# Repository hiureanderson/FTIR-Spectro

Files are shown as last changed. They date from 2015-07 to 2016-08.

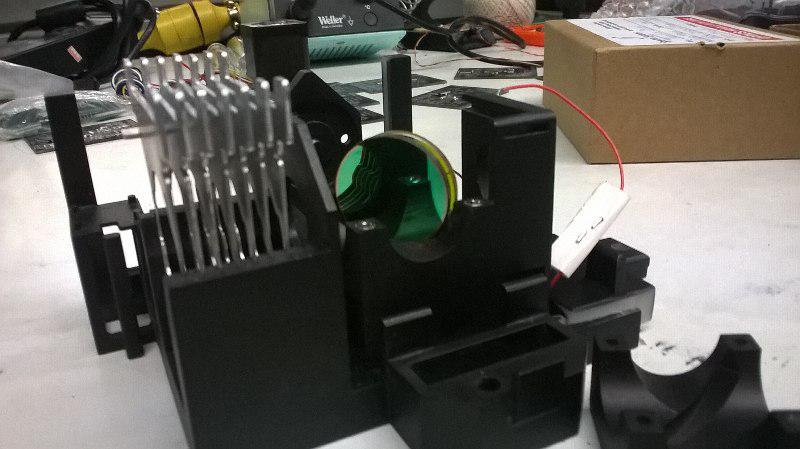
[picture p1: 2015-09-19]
pictures/photo_2015-09-12_13-56-02.jpg

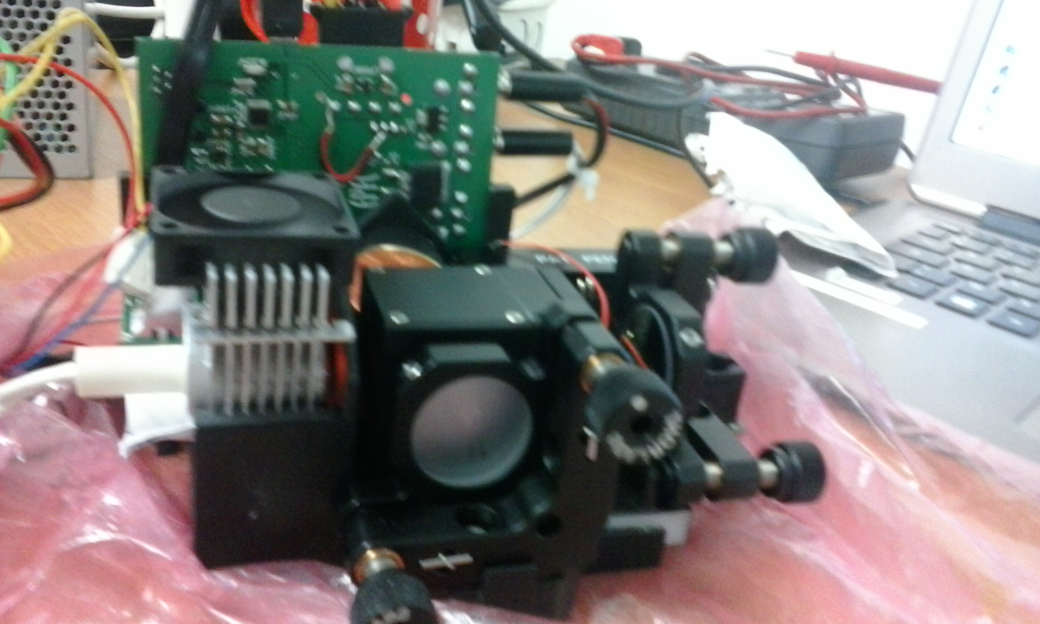
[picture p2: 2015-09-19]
pictures/IMG_20150918_115155.jpg

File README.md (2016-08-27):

# FTIR-Spectro

A DIY Infrared spectrometry project based on michelson interferometry and Fourrier transform analysis
The system relies on a Atmega32u4 MCU as its core and the code is developed using the abstracted Arduino environment.

## What is the current state ?

Last Update: 27.08.2016
The FTIR DIY spectrometer is currently in stanbye and needs students for the project to continue on.
The project is currently based at Octanis Assocation, in the Hackuarium Hackerspace in Renens, Switzerland.
More can be found on these organisations at:

  http://octanis.org   
  http://wiki.hackuarium.ch/w/Main_Page
  
## What needs to be done ?

* Change CAD so that material swelling due to water uptake is taken into account (or change Nylon for a more stable material)
* Retest the stability of the AC-DC network 96V rectifier down to mV oscillations
* Make a proper PCB board for the 96V rectifier with BOM and dedicated documentation and Specs
* Align the mirrors system with a laser
* Test the mirror displacement due to the piezo crystal with a laser and charaterize it
* Program the Atmega MCU to drive the DAC output and test this output voltage (it might be necessary to reorder a board)
* Couple the Atmega MCU to the 0-5V --> 0-96V converter and charaterize the output voltage
* Test the Control of the piezo dilatation with the Atmega and the 0-96V output you charaterized
* Determine if the sensor sensitivity is high enough, if not various options can be explored: change the amplifier resistor bridge, cool the sensor down to -50°C with a Peltier dedicated device to reduce SNR, test a PIR type of sensor, find a more suited sensor.
* Once this stage is complete determine how much light is lost passing in the PE liquid holding cell when empty and scan with the piezo to get the empty cell response (need to program a control loop on the MCU with sensor reading)
* Test the device with different liquids and perform fft on the data provided by the Atmega board to get spectra
* Charaterize for ammonia detection
* Provide a deliverable kit with user manual

Each step must be documented so no work is lost and the community can enjoy the results !!

## Contact

You can contact me concerning the project at quentin.cabrol@gmail.com.
We are currently searching for members to enroll and work on this project

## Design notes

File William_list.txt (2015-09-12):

Order From William

002X 350mA 100VDC --> ok
http://www.alibaba.com/product-detail/50W-constant-current-Single-output-Non_60109745699.html

001X PE HDPE 0.5mm thick A4 sheet (no PVC !! pure PE only !)

010X DIN 934 hex Nut M2
010X DIN 934 hex Nut M4
005X DIN 912 hex Screw M2 13mm
005X DIN 912 hex Screw M2 25mm
005X DIN 912 hex Screw M4 20mm
005X UNC 4-40 screw 7-8mm

200X Thread Forming screw M3 5mm
http://www.alibaba.com/product-detail/Security-pozi-screw-m3x5-stainless-steel_60266052503.html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

Mica sheets (0.1mm 30X20mm) 

1st quote
led power=12usd/pcs X2          24
A4 0.5MM pe roll=2usd/pcs X4    28
Screw and nuts=20usd            48
3d print total=220usd          268
Mica sheet.could I make it 4$  272

/////////////////////////////////////////////////////////////////////////////////////////////////////////////////////////////////

2nd order for Solar Decathlon

20X raspi 2 model B plastic enclosure
20X short USB micro cables 15cm
20X raspi 2 USB power supply
20X 5m length RJ45 cables category 6
20X 16Go Sandisk quality SD card

First quote
20X raspi 2 model B plastic enclosure 2$/pcs		40
20X short USB micro cables    2$/pcs			80
20X raspi 2 USB power supply with line  6$/pcs		200
20X 5m length RJ45 cables category 6  5$/pcs		300
20X 16Go Sandisk quality SD card. 10$/pcs		500

Added to the initial 290 USD first order --> 800 USD
Shipping --> about 100 USD 
William compensation --> 50DUSD 
Grand total 950 USD
With 250 USD dedicated to FTIR

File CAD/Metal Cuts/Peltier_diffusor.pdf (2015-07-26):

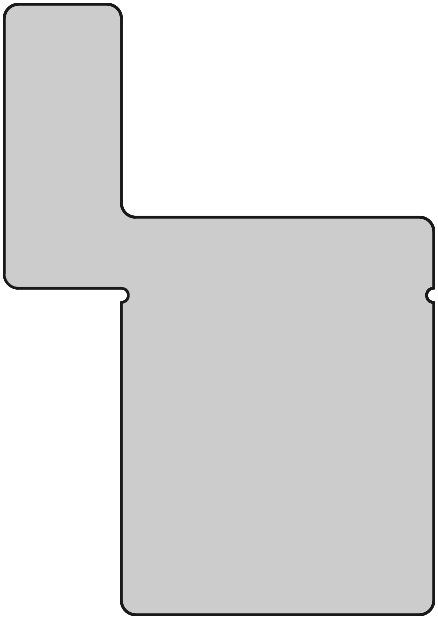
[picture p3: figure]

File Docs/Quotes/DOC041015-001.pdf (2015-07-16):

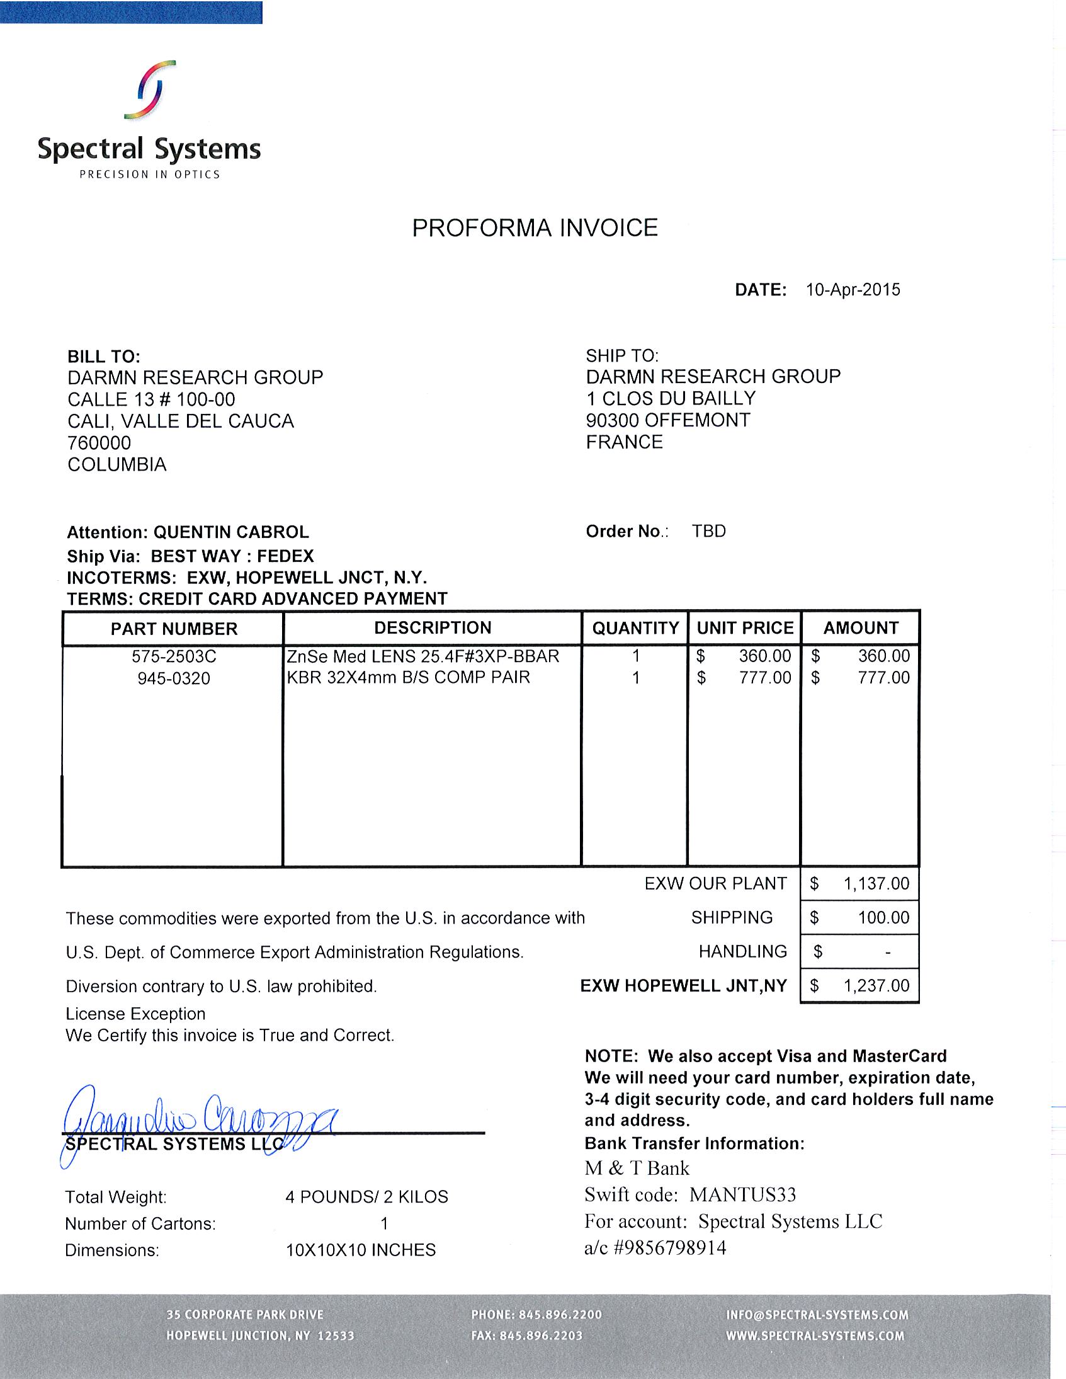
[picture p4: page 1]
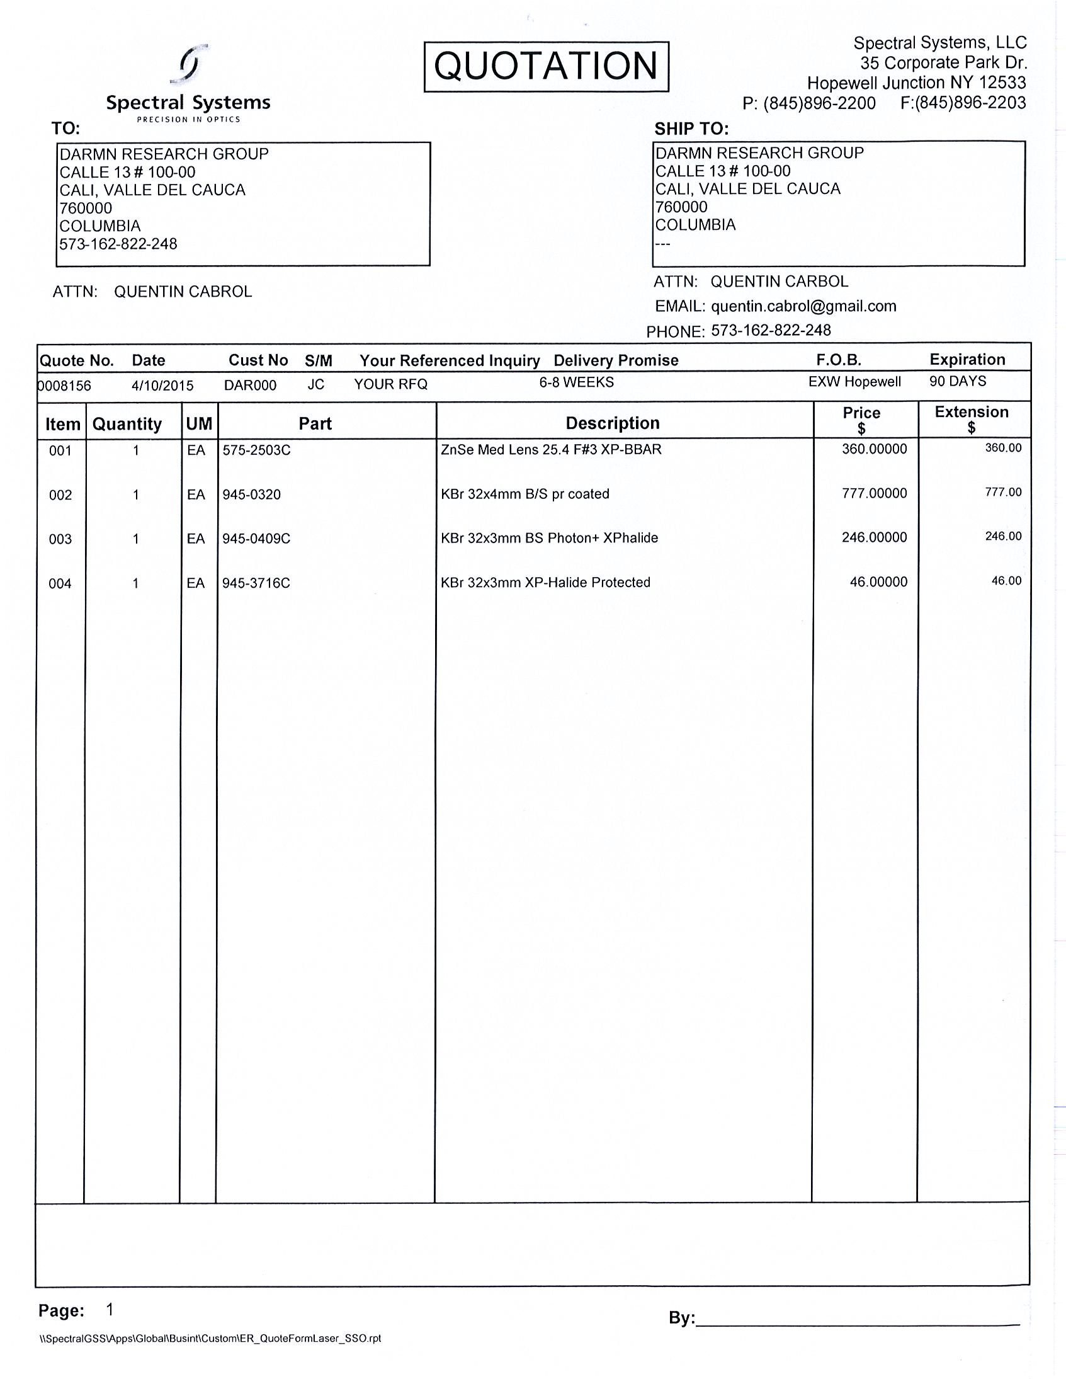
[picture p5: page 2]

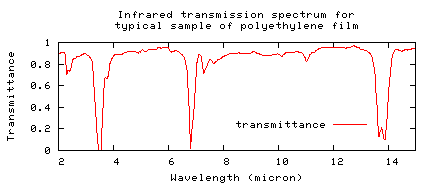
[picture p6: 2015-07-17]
Docs/Datasheets/HDPE_spectrum.png

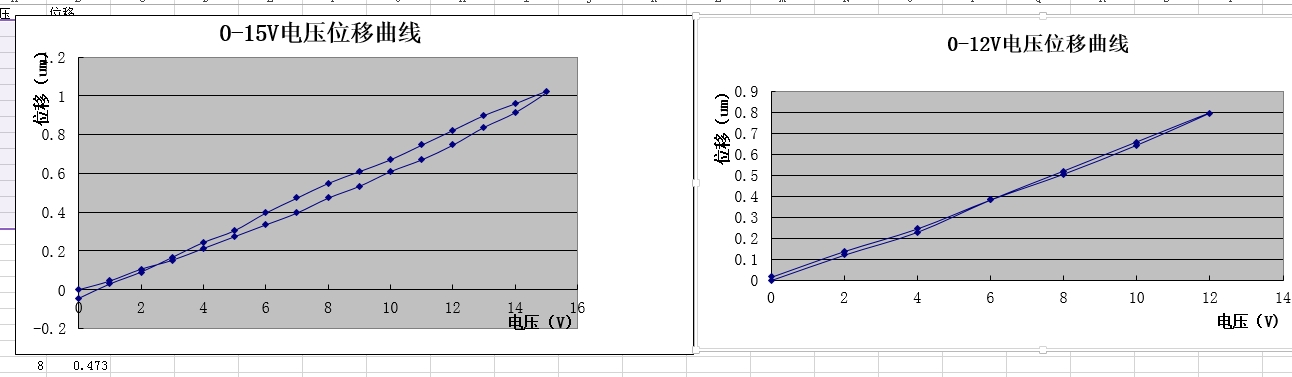
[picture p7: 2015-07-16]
Docs/Datasheets/Piezo_specs.jpg

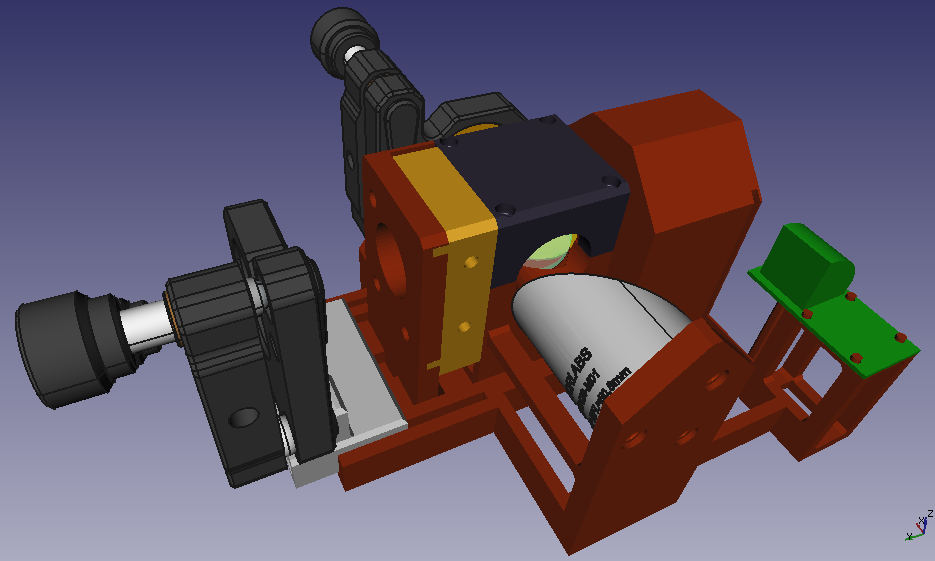
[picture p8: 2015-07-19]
pictures/Full_FTIR.png

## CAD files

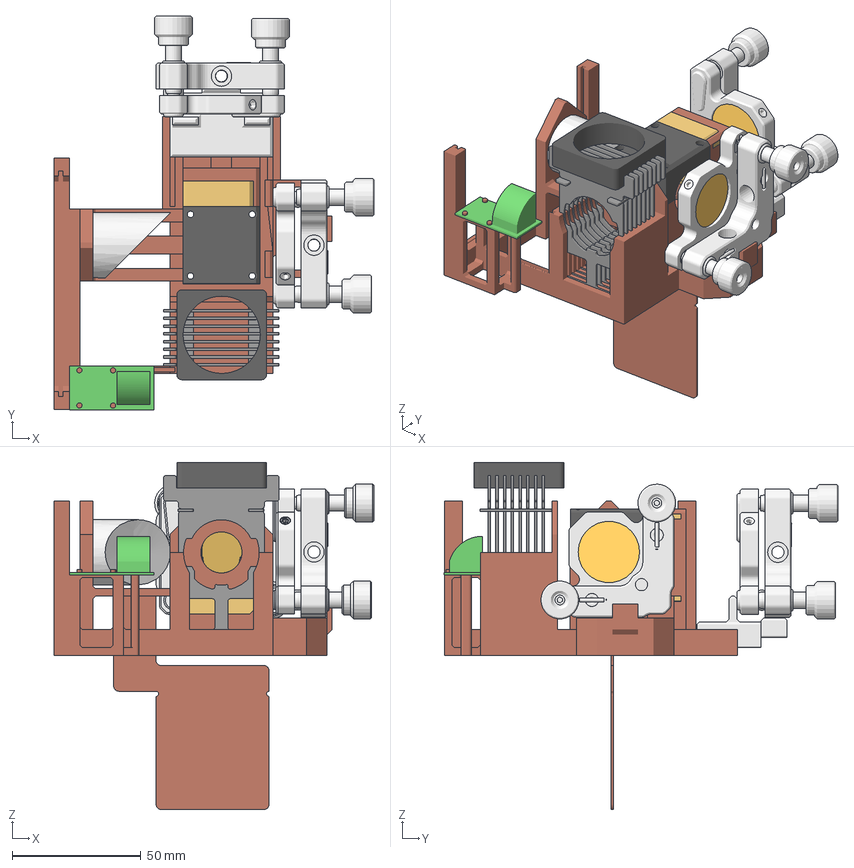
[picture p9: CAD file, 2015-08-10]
CAD/Assembly_6.fcstd
124.4 x 153.1 x 135.0 mm
6628-E0W
6628-E0W001
6628-E0W002
6628-E0W003
6628-E0W004
6628-E0W005
6628-E0W006
6628-E0W007
6628-E0W008
6628-E0W009
6628-E0W010
6628-E0W011
6628-E0W012
6628-E0W013
6628-E0W014
6628-E0W015
6628-E0W016
6628-E0W017
6628-E0W018
6628-E0W019
6628-E0W020
6628-E0W021
6628-E0W022
6628-E0W023
6628-E0W024
6628-E0W025
6628-E0W026
6628-E0W027
6628-E0W028
6628-E0W029
6628-E0W030
6628-E0W031
6628-E0W032
6628-E0W033
TTN034384-E0W
Splitter
Splitter001
Mirror
Mirror001
Holder
Charriot
ZTP115
Splitter_hat
Fan_IR
Heat_slit
Heat_slit001
Heat_slit002
Heat_slit003
Heat_slit004
Heat_slit005
Heat_slit006
Heat_slit007
Heat_slit_holder
Heat_slit_holder001
Peltier_diffusor
Bench_new

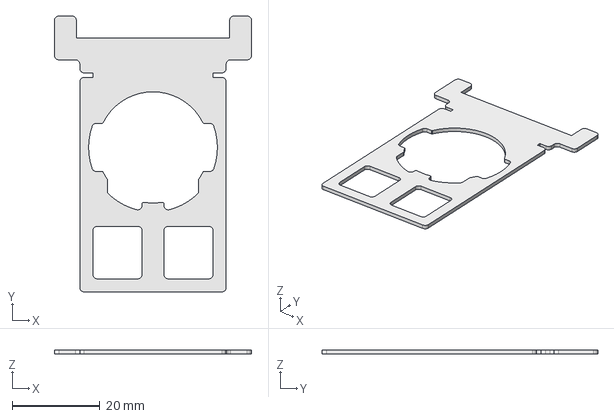
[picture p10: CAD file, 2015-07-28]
CAD/Metal Cuts/MetalCut.fcstd
45.0 x 63.0 x 1.00 mm

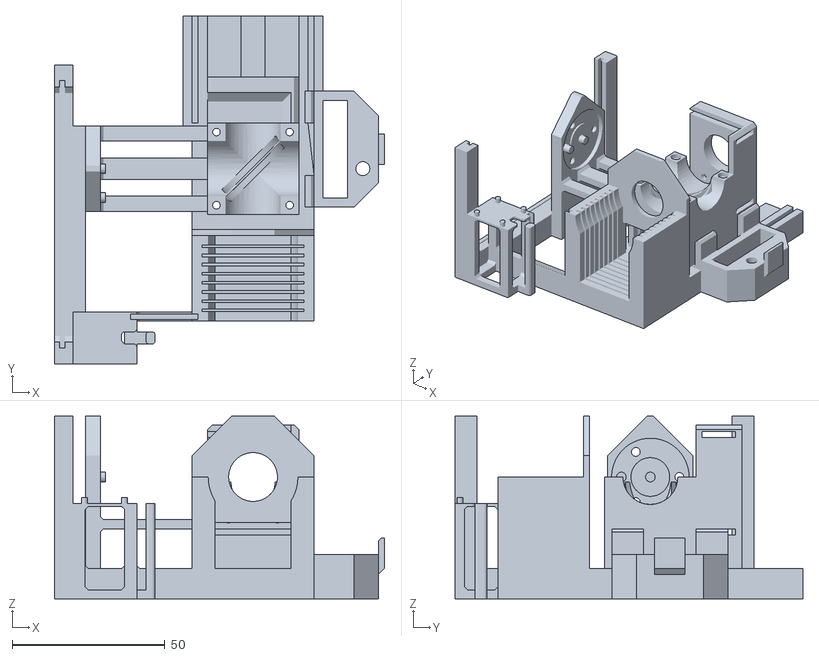
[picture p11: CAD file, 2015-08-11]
CAD/STL/Bench_new.stl
108.2 x 114.0 x 60.0

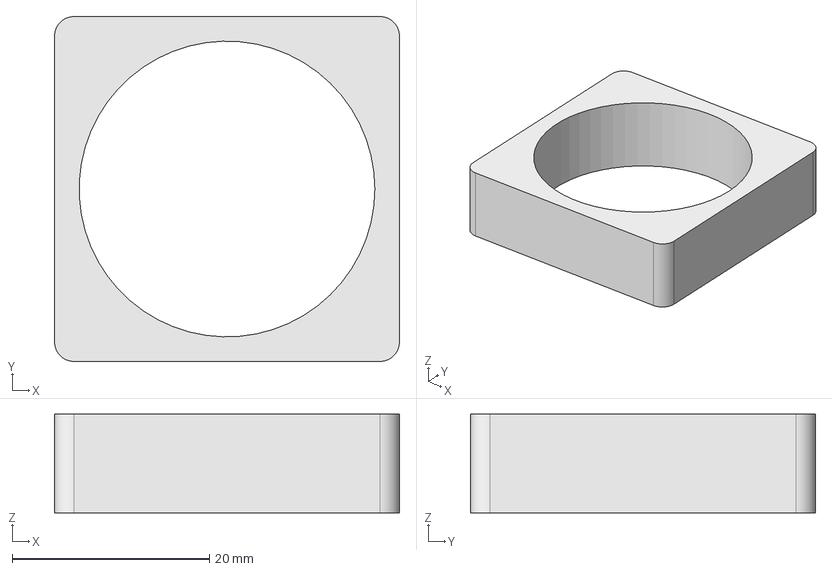
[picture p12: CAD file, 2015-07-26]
CAD/IR_fan.fcstd
35.0 x 35.0 x 10.0 mm

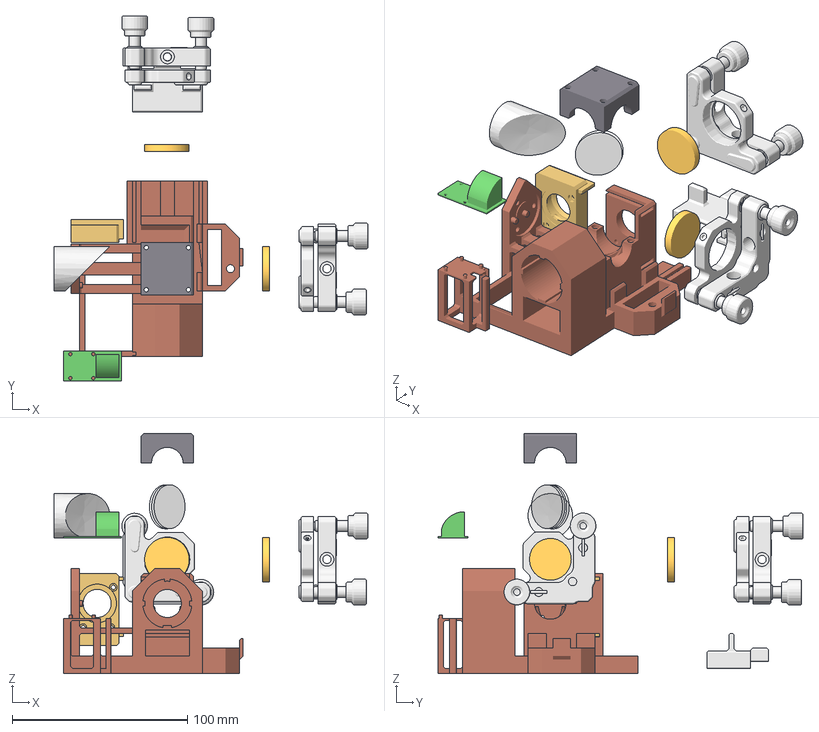
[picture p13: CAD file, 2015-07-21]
CAD/Eclate.fcstd
178.9 x 208.1 x 137.0 mm
6628-E0W
6628-E0W001
6628-E0W002
6628-E0W003
6628-E0W004
6628-E0W005
6628-E0W006
6628-E0W007
6628-E0W008
6628-E0W009
6628-E0W010
6628-E0W011
6628-E0W012
6628-E0W013
6628-E0W014
6628-E0W015
6628-E0W016
6628-E0W017
6628-E0W018
6628-E0W019
6628-E0W020
6628-E0W021
6628-E0W022
6628-E0W023
6628-E0W024
6628-E0W025
6628-E0W026
6628-E0W027
6628-E0W028
6628-E0W029
6628-E0W030
6628-E0W031
6628-E0W032
6628-E0W033
TTN034384-E0W
Splitter
Splitter001
Mirror
Mirror001
Holder
Charriot
ZTP115
Splitter_hat
Bench

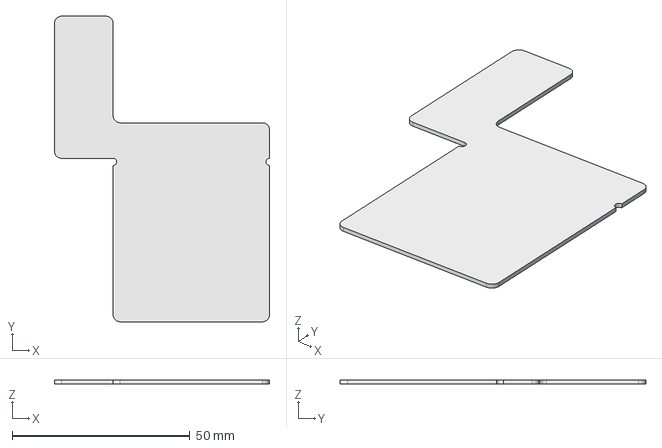
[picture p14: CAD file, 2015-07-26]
CAD/Metal Cuts/Peltier_diffusor.fcstd
60.5 x 86.0 x 1.00 mm

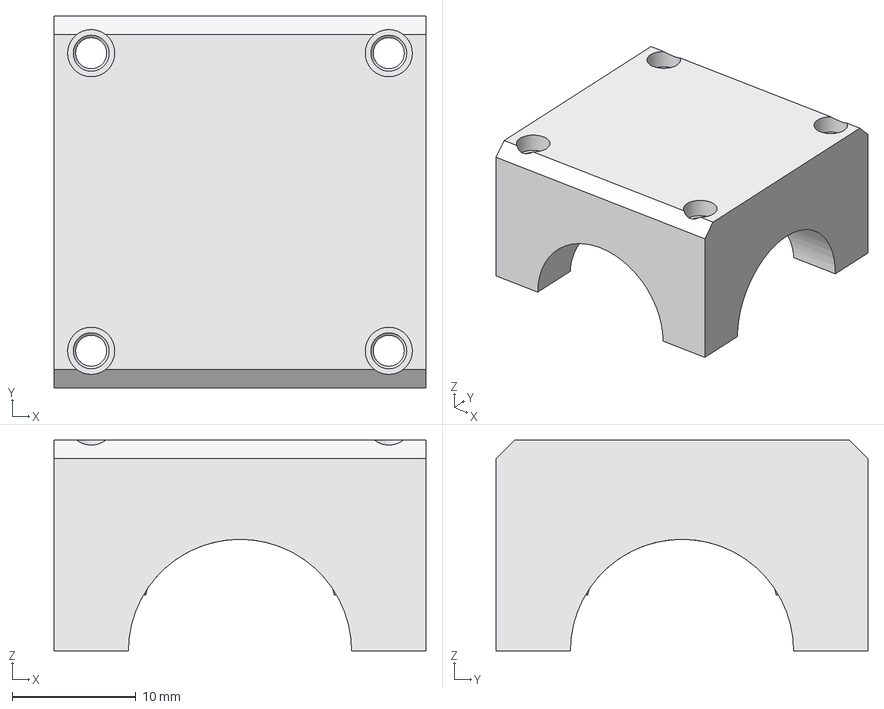
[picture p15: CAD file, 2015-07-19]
CAD/Splitter_Hat_1.fcstd
30.0 x 30.0 x 17.0 mm

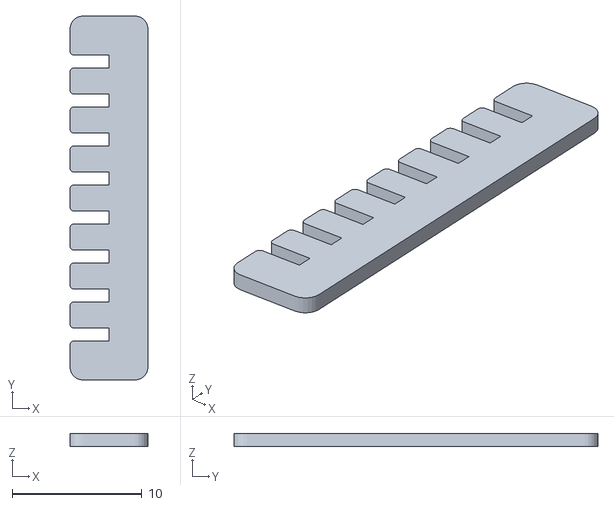
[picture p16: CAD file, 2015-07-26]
CAD/STL/Heat_slit_holder.stl
6.00 x 28.0 x 1.00

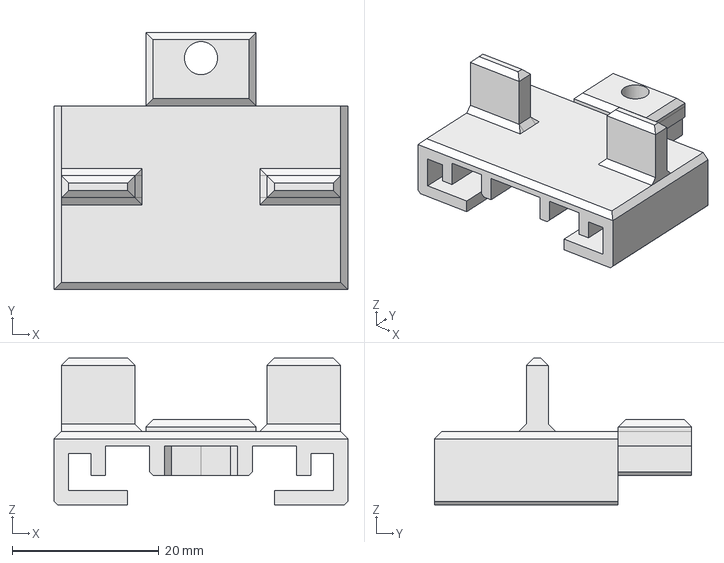
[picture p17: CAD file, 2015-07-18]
CAD/Charriot_2.fcstd
40.0 x 35.0 x 20.0 mm

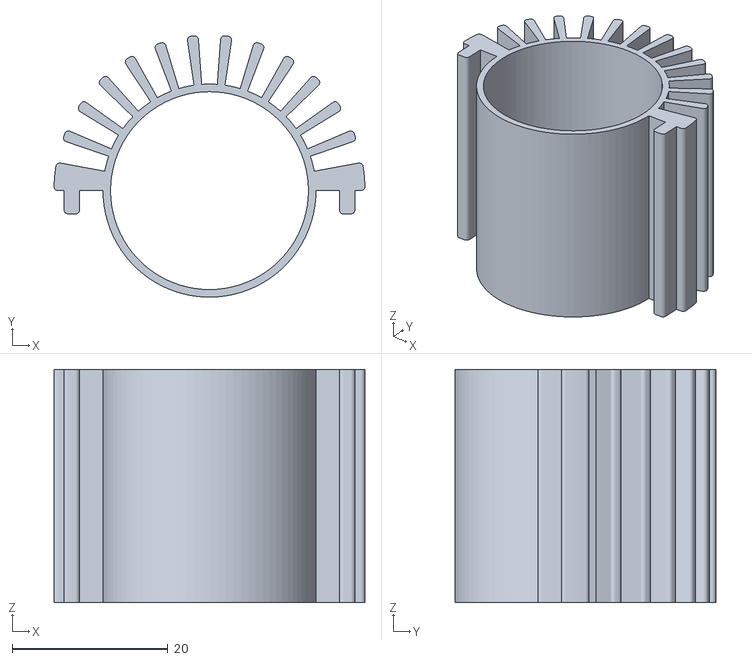
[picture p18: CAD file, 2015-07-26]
CAD/STL/Heat_sink.stl
40.0 x 33.6 x 30.0

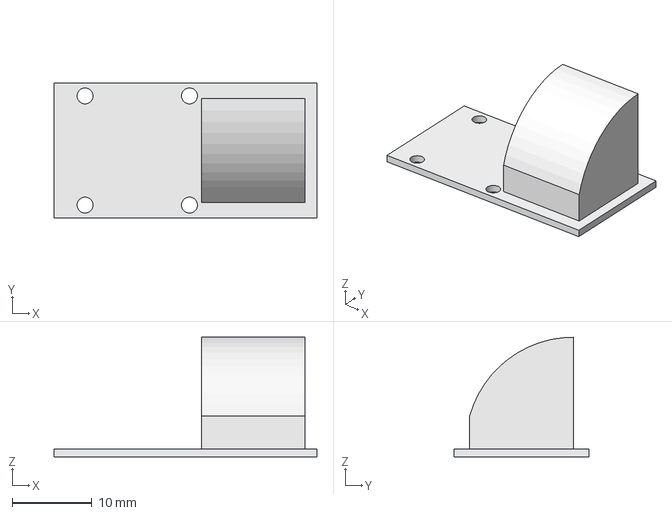
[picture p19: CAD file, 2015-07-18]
CAD/Sensor_ZTP115.fcstd
33.0 x 17.0 x 15.0 mm

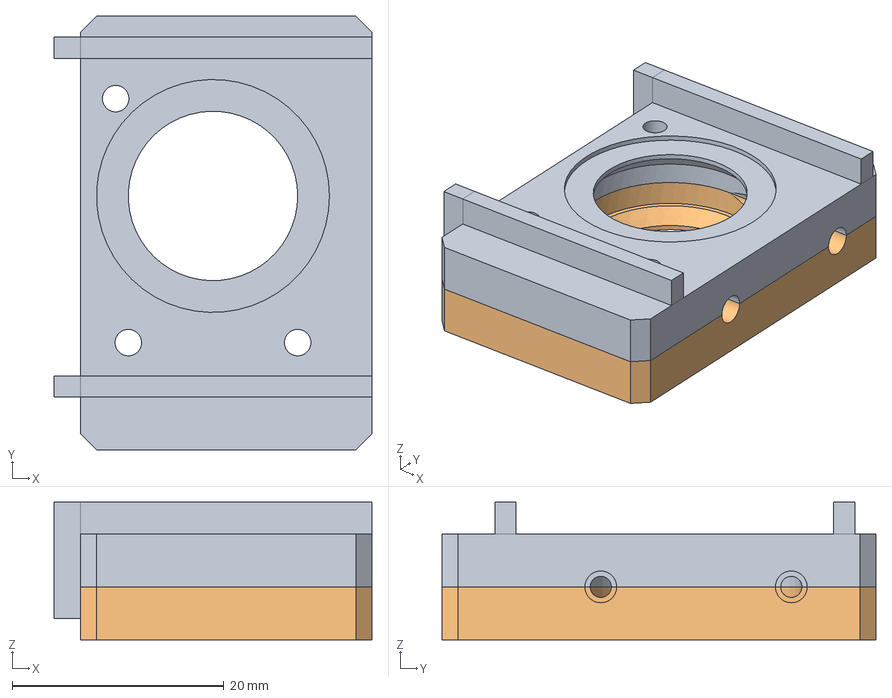
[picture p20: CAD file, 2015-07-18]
CAD/Sample_holder_3.fcstd
30.0 x 41.0 x 13.0 mm

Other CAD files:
CAD/Metal Cuts/Heat_slit.dwg
CAD/STL/Fan_IR.stl
CAD/STL/Peltier_diffusor.stl
CAD/Metal Cuts/Heat_slit_holder.dwg
CAD/Metal Cuts/Slits_holder.fcstd
CAD/STL/Heat_slit.stl
CAD/FTIR.fcstd
CAD/Metal Cuts/Peltier_diffusor.dwg
CAD/Mirror.fcstd
CAD/STL/Charriot.stl
CAD/STL/Holder.stl
CAD/STL/KM100-Step.step
CAD/STL/MPD129-M01-Step.step
CAD/STL/Mirror.stl
CAD/STL/Splitter.stl
CAD/STL/Splitter_hat.stl
CAD/STL/ZTP115.stl
CAD/Sample_holder_2.fcstd
CAD/Splitter.fcstd

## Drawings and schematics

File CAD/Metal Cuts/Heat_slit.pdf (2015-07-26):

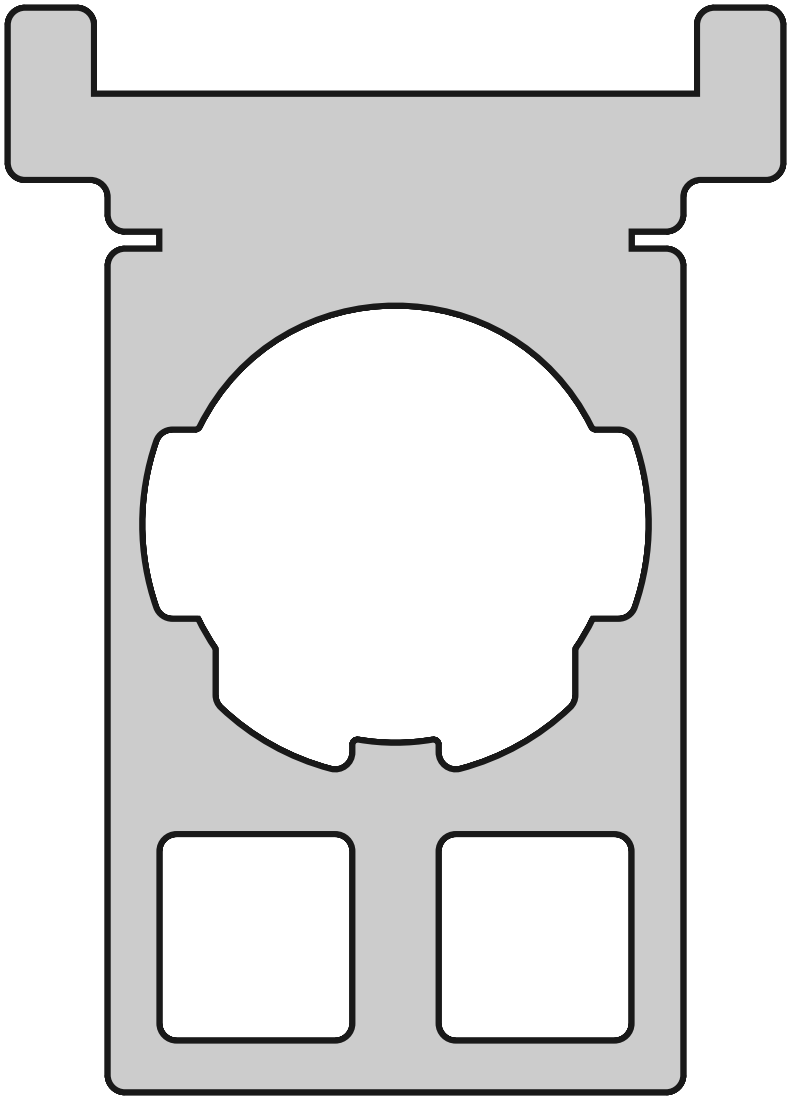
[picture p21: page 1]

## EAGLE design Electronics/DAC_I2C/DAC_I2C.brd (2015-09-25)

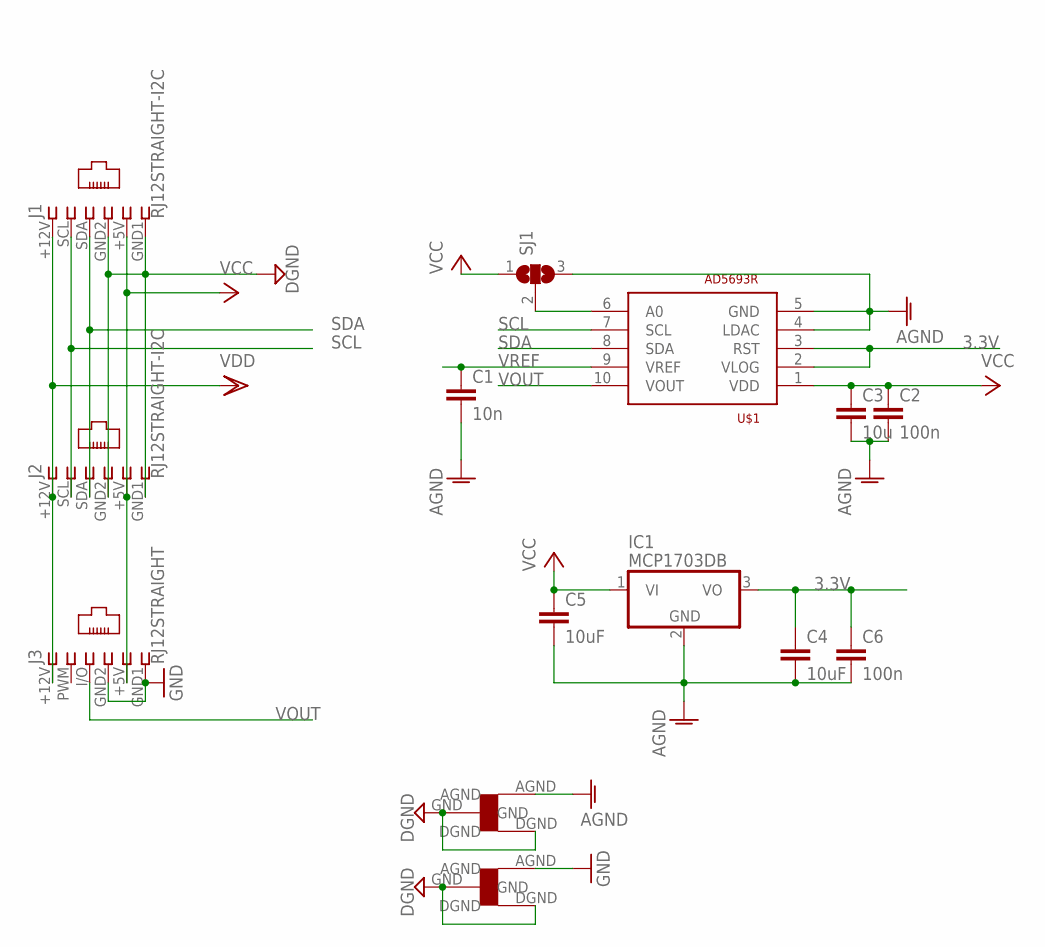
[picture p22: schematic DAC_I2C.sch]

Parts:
C1: 10n; C1206
C2, C6: 100n; C1206
C3: 10u; C1206
C4, C5: 10uF; C1206
IC1: MCP1703DB; SOT223
J1, J2: RJ12STRAIGHT-I2C; RJ12-STRAIGHT-I2C
J3: RJ12STRAIGHT; RJ12-STRAIGHT
SJ1: SJ2W; SJ_2
U$1: AD5693R; MSOP10
U$2, U$5: STARGND; STAR

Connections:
3.3V: C4.1, C6.1, IC1.3 (VO), U$1.2 (VLOG), U$1.3 (RST)
AGND: C1.2, C2.2, C3.2, C4.2, C5.2, C6.2, IC1.2 (GND), SJ1.3, U$1.4 (LDAC), U$1.5 (GND), U$5.AGND
DGND: J1.GND1 (6), J1.GND2 (4), J2.GND1 (6), J2.GND2 (4), U$2.DGND, U$2.GND, U$5.DGND, U$5.GND
GND: J3.GND1 (6), J3.GND2 (4), U$2.AGND
unnamed: SJ1.2, U$1.6 (A0)
SCL: J1.SCL (2), J2.SCL (2), U$1.7 (SCL)
SDA: J1.SDA (3), J2.SDA (3), U$1.8 (SDA)
VCC: C2.1, C3.1, C5.1, IC1.1 (VI), J1.+5V (5), J2.+5V (5), J3.+5V (5), SJ1.1, U$1.1 (VDD)
VDD: J1.+12V (1), J2.+12V (1), J3.+12V (1)
VOUT: J3.I/O (3), U$1.10 (VOUT)
VREF: C1.1, U$1.9 (VREF)

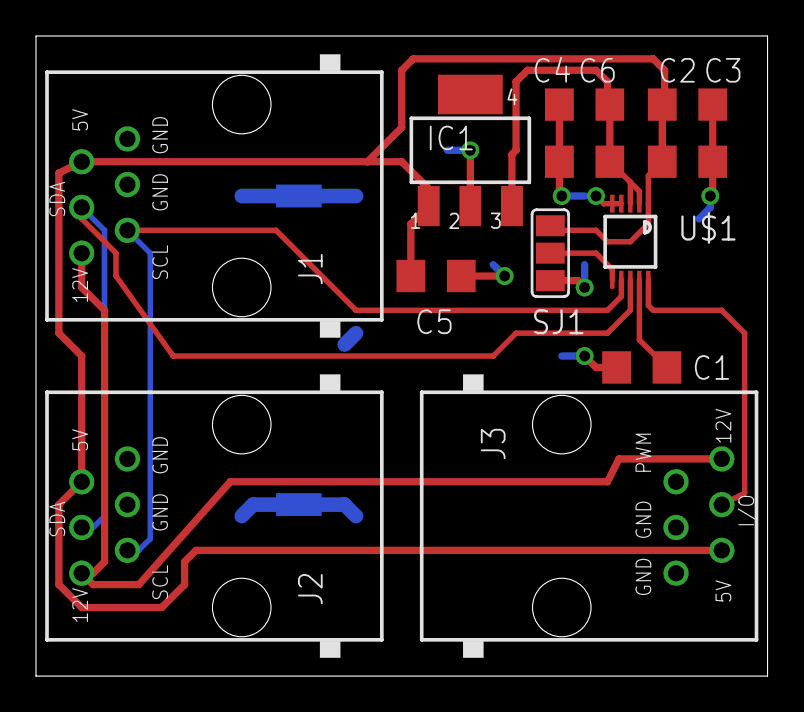
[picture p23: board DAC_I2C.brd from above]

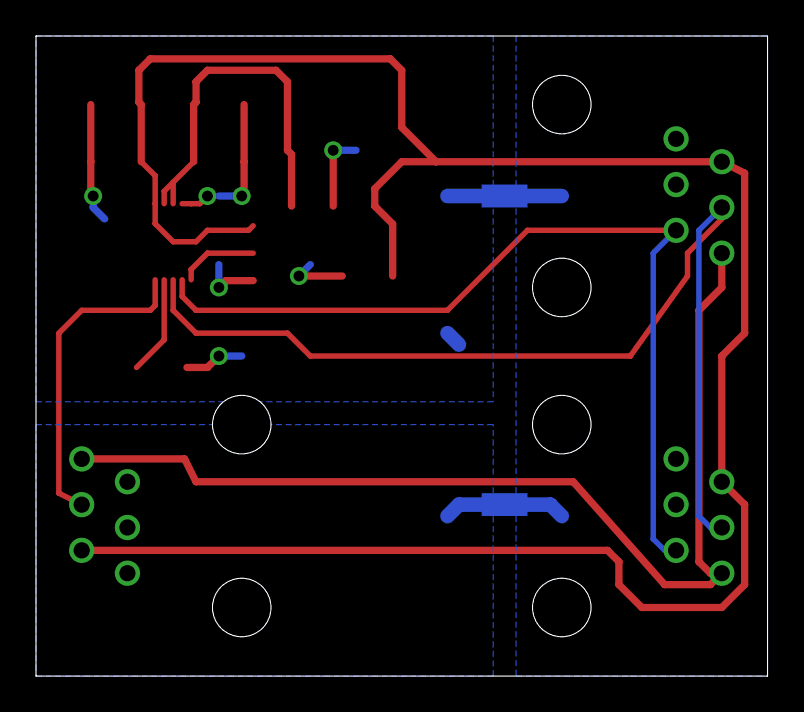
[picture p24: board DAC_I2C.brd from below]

Board: 2 copper layers, 40.6 x 35.6 mm, 14 parts (2 on the bottom side), 11 nets.

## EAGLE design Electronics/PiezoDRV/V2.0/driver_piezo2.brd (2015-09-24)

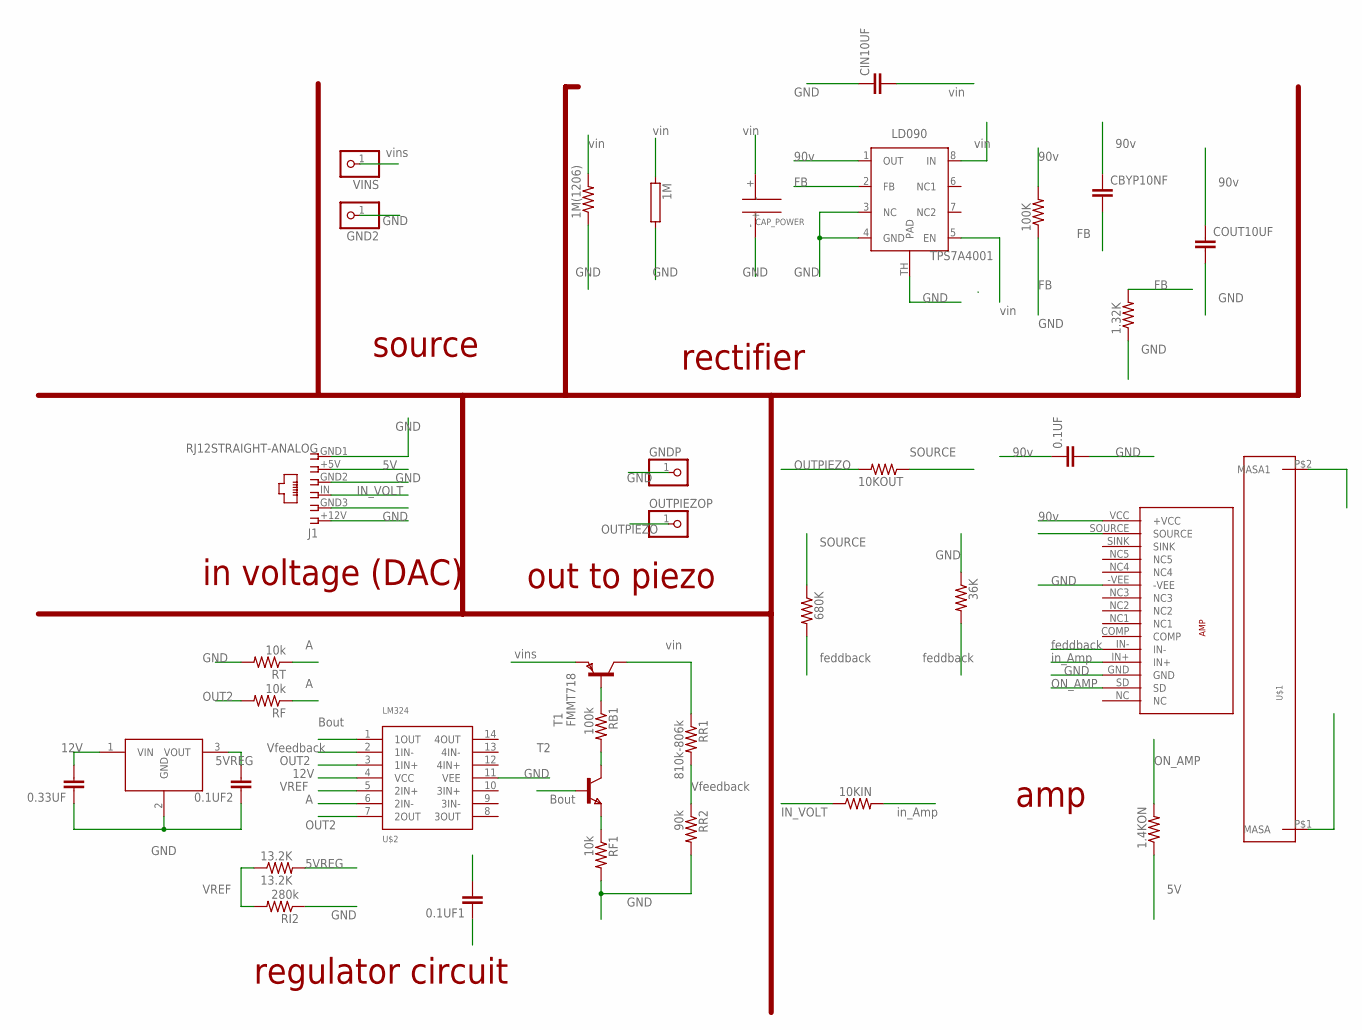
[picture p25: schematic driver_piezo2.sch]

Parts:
0.1UF, 0.1UF1, 0.1UF2, 0.33UF: C-EUC1206; C1206
1.4KON, 1.32K, 1M(1206), 10KIN, 10KOUT, 36K, 100K, 680K: R-US_R1206; R1206
1M: RCA0002; CA0002
13.2K: 13.2K; R1206
AMP: POWER_AMP_LME49811TB
CAP_POWER: CAP200VCAP200V; CAP200V
CBYP10NF: C-EUC1206; C1206
CIN10UF: C-EUC1206; C1206
COUT10UF: C-EUC1206; C1206
GND2: PINHD-1X1; 1X01
GNDP: PINHD-1X1; 1X01
J1: RJ12STRAIGHT-ANALOG; RJ12-STRAIGHT-ANALOG
LD090: TPS7A4001; S-PDSO-G08
OUTPIEZOP: PINHD-1X1; 1X01
RB1: 100k; R1206
RF, RF1: 10k; R1206
RI2: 280k; R1206
RR1: 810k-806k; R1206
RR2: 90k; R1206
RT: 10k; R1206
T1: FMMT718; SOT-23
T2: NPNSOT89; SOT89
U$1: DISIPADOR
U$2: LM324; SO14
U$3: 7805; TO220
VINS: PINHD-1X1; 1X01

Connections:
1OUT: T2.1 (B), U$2.1 (1OUT)
2IN+: 13.2K.1, RI2.2, U$2.5 (2IN+)
2IN-: RF.1, RT.1, U$2.6 (2IN-)
2OUT: RF.2, U$2.3 (1IN+), U$2.7 (2OUT)
5V: 1.4KON.1, J1.+5V (5)
5VOP: 0.1UF2.2, 13.2K.2, U$3.3 (VOUT)
12V: 0.1UF1.2, 0.33UF.2, J1.+12V (1), U$2.4 (VCC), U$3.1 (VIN)
B: 36K.2, 680K.2, AMP.IN-
FB: 1.32K.2, 100K.1, CBYP10NF.2, LD090.2 (FB)
GND: 0.1UF.2, 0.1UF1.1, 0.1UF2.1, 0.33UF.1, 1.32K.1, 1M.2, 1M(1206).1, 36K.1, AMP.-VEE, AMP.GND, CAP_POWER.-, CIN10UF.1, COUT10UF.2, GND2.1, GNDP.1, J1.GND1 (6), J1.GND2 (4), J1.GND3 (2), LD090.3 (NC), LD090.4 (GND), LD090.TH (PAD), RF1.2, RI2.1, RR2.2, RT.2, U$1.P$1 (MASA), U$1.P$2 (MASA1), U$2.11 (VEE), U$3.2 (GND)
IN_AMP: 10KIN.2, AMP.IN+
IN_VOLTAGE: 10KIN.1, J1.IN (3)
unnamed: RB1.2, T2.2 (C), T2.2@1 (C)
unnamed: RB1.1, T1.3 (B)
unnamed: RF1.1, T2.3 (E)
ON: 1.4KON.2, AMP.SD
OUT_PIEZO: 10KOUT.2, OUTPIEZOP.1
SOURCE: 10KOUT.1, 680K.1, AMP.SOURCE
V90: 0.1UF.1, 100K.2, AMP.VCC (+VCC), CBYP10NF.1, COUT10UF.1, LD090.1 (OUT)
VF: RR1.2, RR2.1, U$2.2 (1IN-)
VIN: 1M.1, 1M(1206).2, CAP_POWER.+, CIN10UF.2, LD090.5 (EN), LD090.8 (IN), RR1.1, T1.1 (C)
VINS: T1.2 (E), VINS.1

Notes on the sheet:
source
rectifier
out to piezo
amp
vins
vin
90v
GND
OUTPIEZO
IN_VOLT
ON_AMP
feddback
in voltage (DAC)
in_Amp
SOURCE
regulator circuit
Vfeedback
Bout
OUT2
12V
VREF
5VREG

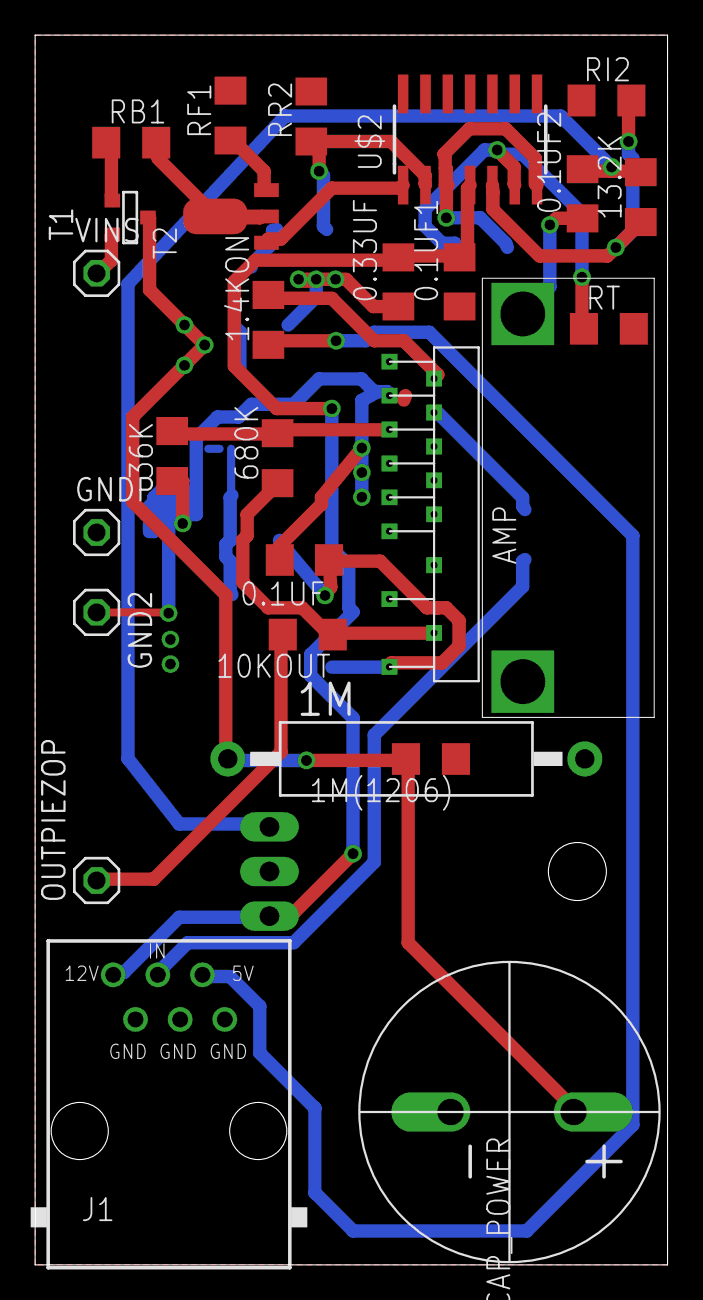
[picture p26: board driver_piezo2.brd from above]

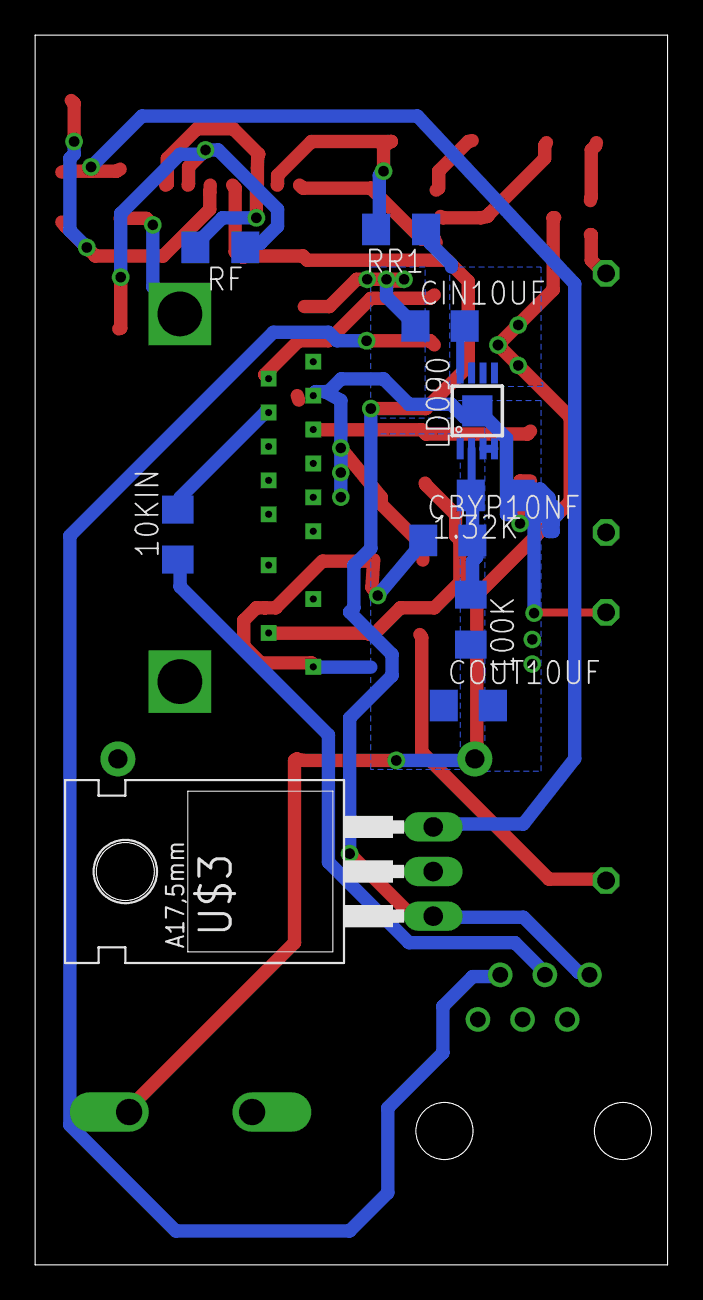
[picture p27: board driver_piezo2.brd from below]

Board: 2 copper layers, 36.0 x 70.0 mm, 37 parts (10 on the bottom side), 22 nets.

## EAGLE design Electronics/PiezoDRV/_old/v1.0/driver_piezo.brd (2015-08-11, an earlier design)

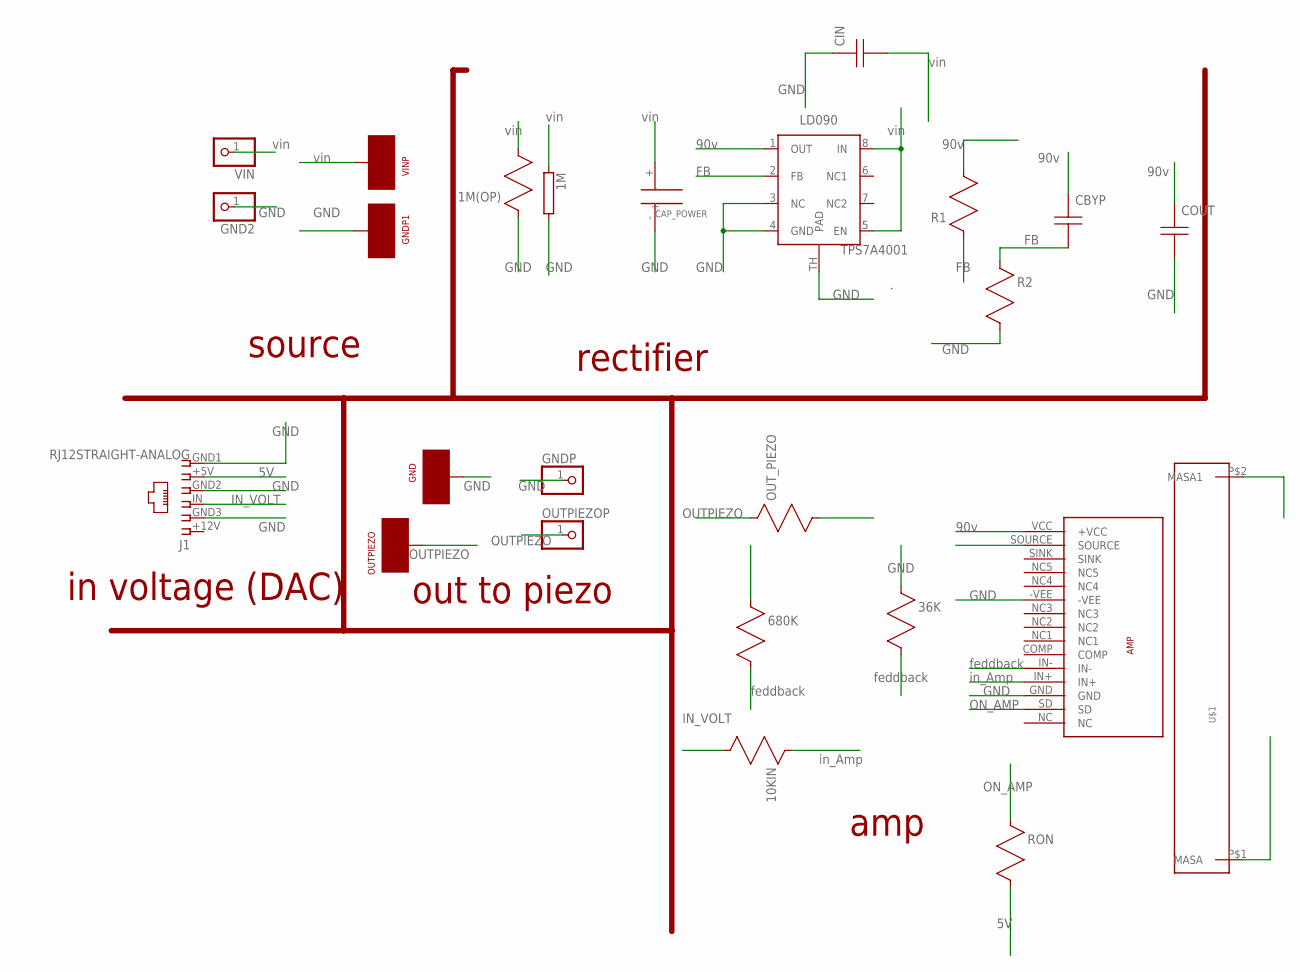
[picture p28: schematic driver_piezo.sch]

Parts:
1M: RCA0002; CA0002
1M(OP), 10KIN, 36K, 680K: RES; R0805
AMP: POWER_AMP_LME49811TB
CAP_POWER: CAP200VCAP200V; CAP200V
CBYP: CAP; C0805
CIN: CAP; C0805
COUT: CAP; C0805
GND: PAD
GND2: PINHD-1X1; 1X01
GNDP: PINHD-1X1; 1X01
GNDP1: PAD
J1: RJ12STRAIGHT-ANALOG; RJ12-STRAIGHT-ANALOG
LD090: TPS7A4001; S-PDSO-G08
OUTPIEZO: PAD
OUTPIEZOP: PINHD-1X1; 1X01
OUT_PIEZO: RES; R0805
R1, R2: RES; R0805
RON: RES; R0805
U$1: DISIPADOR
VIN: PINHD-1X1; 1X01
VINP: PAD

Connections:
5V: J1.+5V (5), RON.2 (B)
B: 36K.2 (B), 680K.2 (B), AMP.IN-
FB: CBYP.2 (B), LD090.2 (FB), R1.1 (A), R2.1 (A)
GND: 1M.2, 1M(OP).1 (A), 36K.1 (A), AMP.-VEE, AMP.GND, CAP_POWER.-, CIN.1 (A), COUT.2 (B), GND.P$1, GND2.1, GNDP.1, GNDP1.P$1, J1.GND1 (6), J1.GND2 (4), J1.GND3 (2), LD090.3 (NC), LD090.4 (GND), LD090.TH (PAD), R2.2 (B), U$1.P$1 (MASA), U$1.P$2 (MASA1)
IN_AMP: 10KIN.1 (A), AMP.IN+
IN_VOLTAGE: 10KIN.2 (B), J1.IN (3)
ON: AMP.SD, RON.1 (A)
OUT_PIEZO: OUTPIEZO.P$1, OUTPIEZOP.1, OUT_PIEZO.1 (A)
SOURCE: 680K.1 (A), AMP.SOURCE, OUT_PIEZO.2 (B)
V90: AMP.VCC (+VCC), CBYP.1 (A), COUT.1 (A), LD090.1 (OUT), R1.2 (B)
VIN: 1M.1, 1M(OP).2 (B), CAP_POWER.+, CIN.2 (B), LD090.5 (EN), LD090.8 (IN), VIN.1, VINP.P$1

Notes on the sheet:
source
rectifier
out to piezo
amp
vin
90v
GND
OUTPIEZO
IN_VOLT
ON_AMP
feddback
in voltage (DAC)
in_Amp

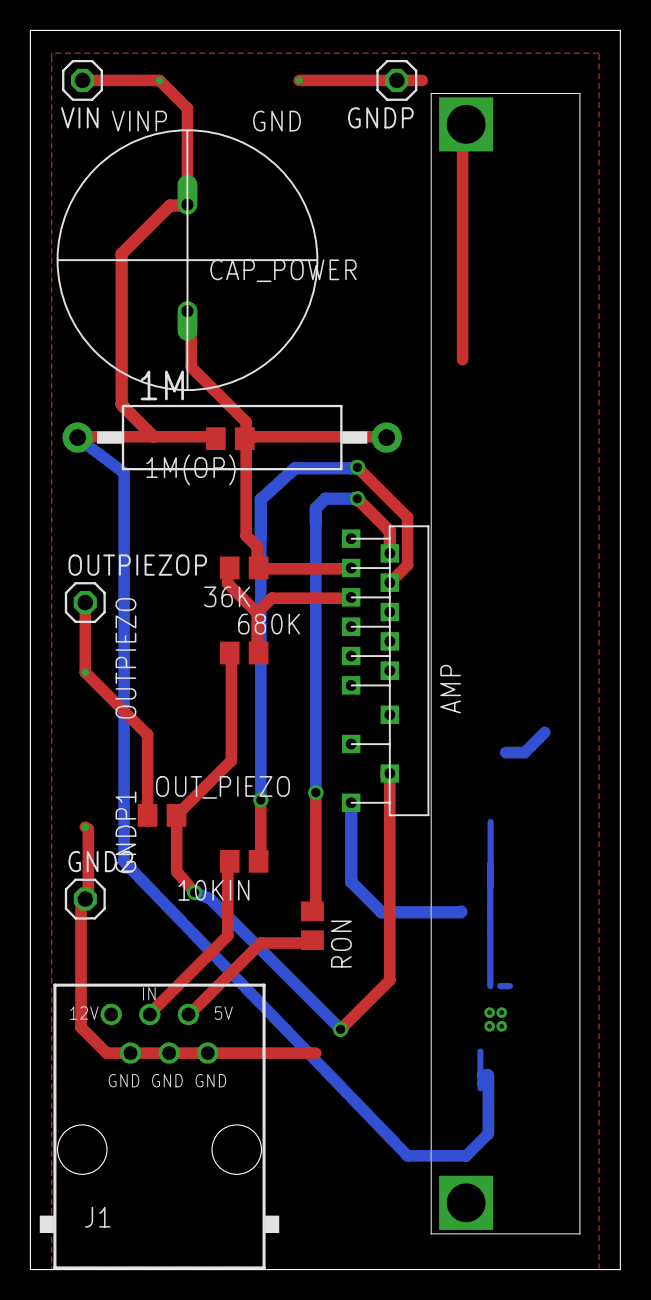
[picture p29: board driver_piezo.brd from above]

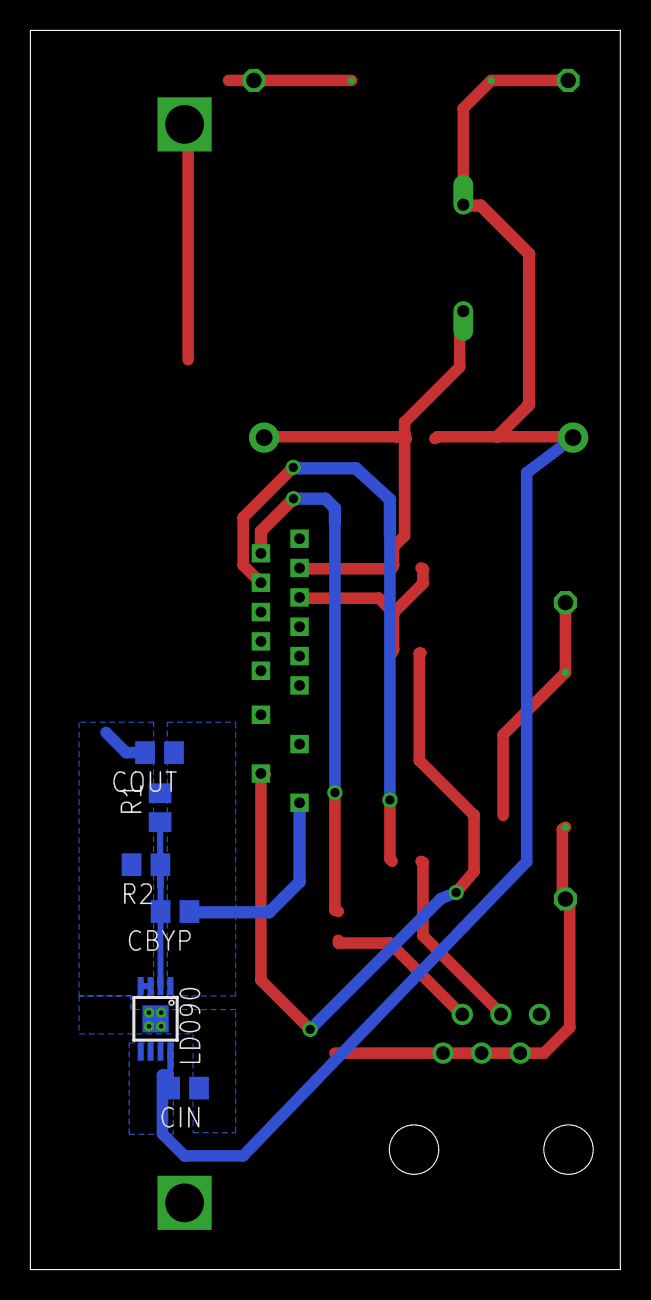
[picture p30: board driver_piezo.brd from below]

Board: 2 copper layers, 38.8 x 81.5 mm, 25 parts (6 on the bottom side), 11 nets.

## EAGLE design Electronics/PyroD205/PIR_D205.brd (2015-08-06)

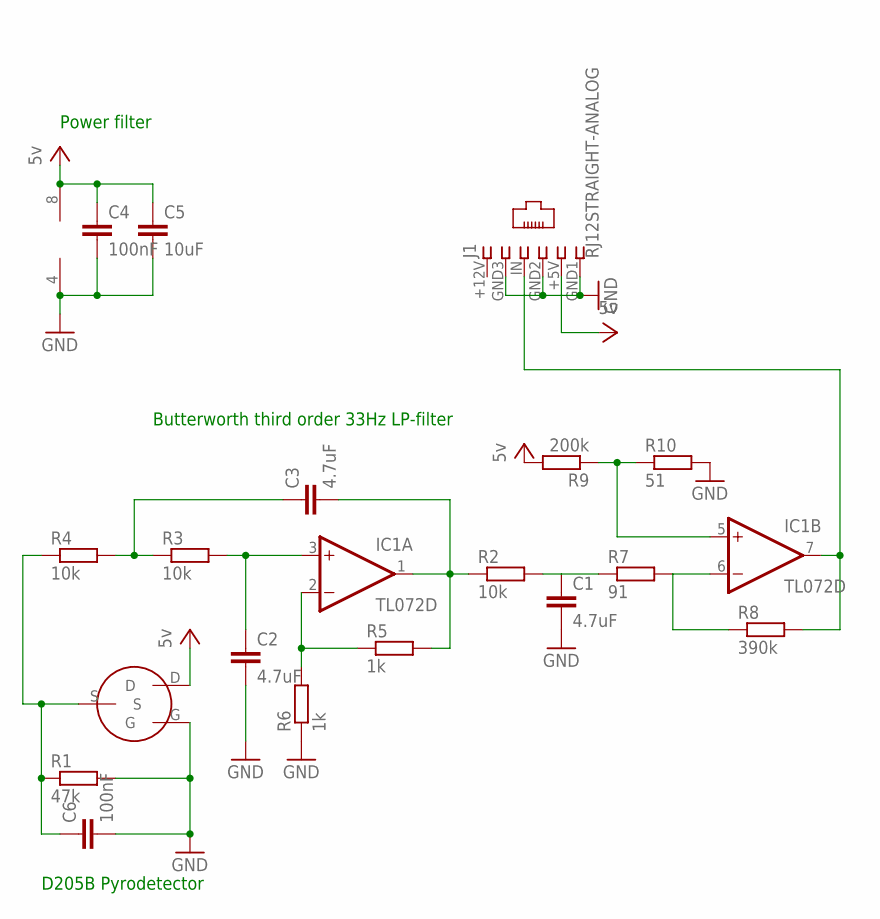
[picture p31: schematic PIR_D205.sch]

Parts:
C1, C2, C3: 4.7uF; C1206
C4, C6: 100nF; C1206
C5: 10uF; C1206
IC1: TL072D; SO08
J1: RJ12STRAIGHT-ANALOG; RJ12-STRAIGHT-ANALOG
R1: 47k; R1206
R2, R3, R4: 10k; R0805
R5, R6: 1k; R0805
R7: 91; R1206
R8: 390k; R1206
R9: 200k; R1206
R10: 51; R1206
U$1: D205B; TO5

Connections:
GND: C1.2, C2.2, C4.2, C5.2, C6.2, IC1.4 (V-), J1.GND1 (6), J1.GND2 (4), J1.GND3 (2), R1.2, R6.1, R10.2, U$1.G
unnamed: C6.1, R1.1, R4.1, U$1.S
unnamed: C3.2, IC1.1 (OUT), R2.1, R5.2
unnamed: IC1.2 (-IN), R5.1, R6.2
unnamed: C1.1, R2.2, R7.1
unnamed: C2.1, IC1.3 (+IN), R3.2
unnamed: C3.1, R3.1, R4.2
unnamed: IC1.6 (-IN), R7.2, R8.1
unnamed: IC1.7 (OUT), J1.IN (3), R8.2
unnamed: IC1.5 (+IN), R9.1, R10.1
VCC: C4.1, C5.1, IC1.8 (V+), J1.+5V (5), R9.2, U$1.D

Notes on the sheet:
Butterworth third order 33Hz LP-filter
D205B Pyrodetector
Power filter

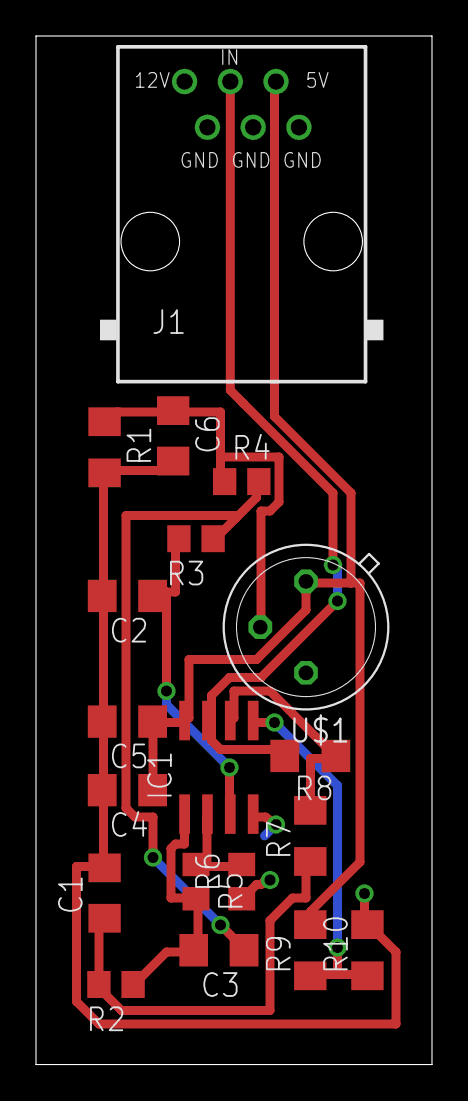
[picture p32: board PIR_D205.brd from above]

Board: 2 copper layers, 22.0 x 57.1 mm, 19 parts (0 on the bottom side), 11 nets.

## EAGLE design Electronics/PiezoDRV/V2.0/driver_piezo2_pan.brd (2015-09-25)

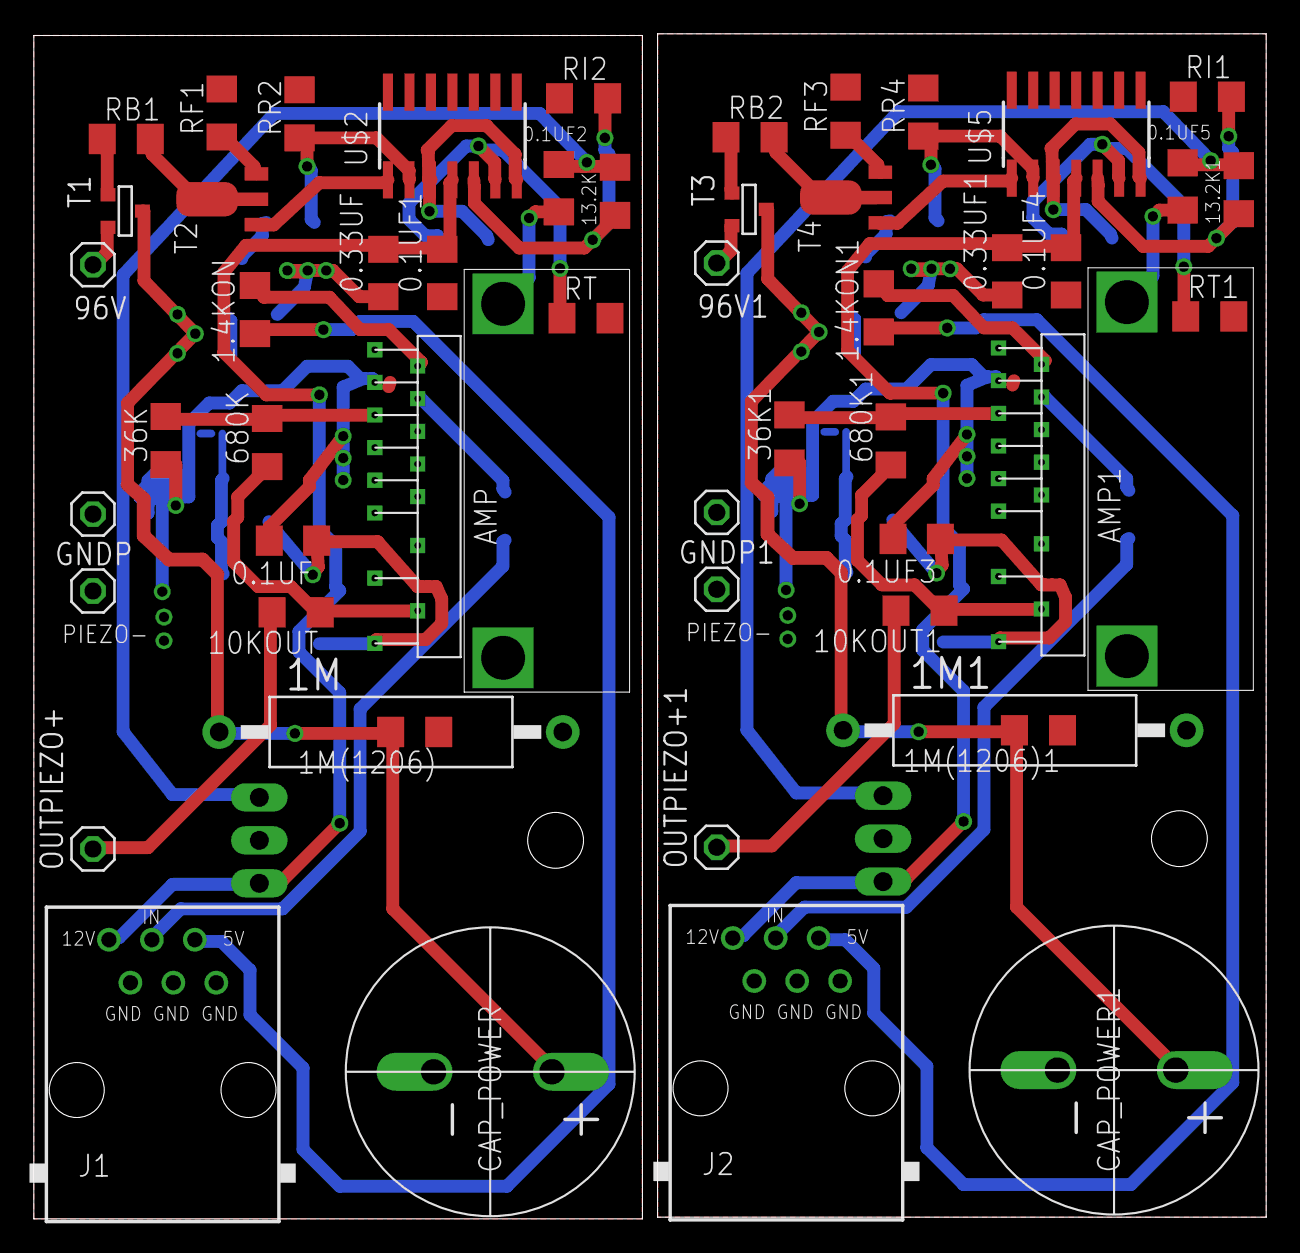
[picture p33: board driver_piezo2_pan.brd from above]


Board: 2 copper layers, 72.9 x 70.1 mm, 74 parts (20 on the bottom side), 44 nets.

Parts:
0.1UF, 0.1UF1, 0.1UF2, 0.1UF3, 0.1UF4, 0.1UF5, 0.33UF, 0.33UF1: C1206
1.4KON, 1.4KON1, 1.32K, 1.32K1, 1M(1206), 1M(1206)1, 10KIN, 10KIN1, 10KOUT, 10KOUT1, 36K, 36K1, 100K, 100K1, 680K, 680K1: R1206
1M, 1M1: CA0002
13.2K, 13.2K1: 13.2K; R1206
96V, 96V1: 1X01
AMP, AMP1: POWER_AMP_LME49811TB
CAP_POWER, CAP_POWER1: CAP200VCAP200V; CAP200V
CBYP10NF, CBYP10NF1: C1206
CIN10UF, CIN10UF1: C1206
COUT10UF, COUT10UF1: C1206
GND1, GND2: 1X01
GNDP, GNDP1: 1X01
J1, J2: RJ12STRAIGHT-ANALOG; RJ12-STRAIGHT-ANALOG
LD001, LD090: TPS7A4001; S-PDSO-G08
OUTPIEZO+, OUTPIEZO+1: 1X01
RB1, RB2: 100k; R1206
RF, RF1, RF2, RF3: 10k; R1206
RI1, RI2: 280k; R1206
RR1, RR3: 810k-806k; R1206
RR2, RR4: 90k; R1206
RT, RT1: 10k; R1206
T1, T3: FMMT718; SOT-23
T2, T4: SOT89
U$1, U$4: DISIPADOR
U$2, U$5: LM324; SO14
U$3, U$6: 7805; TO220

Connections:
1OUT: T2.1, U$2.1
1OUT1: T4.1, U$5.1
2IN+: 13.2K.1, RI2.2, U$2.5
2IN+1: 13.2K1.1, RI1.2, U$5.5
2IN-: RF.1, RT.1, U$2.6
2IN-1: RF2.1, RT1.1, U$5.6
2OUT: RF.2, U$2.3, U$2.7
2OUT1: RF2.2, U$5.3, U$5.7
5V: 1.4KON.1, J1.+5V
5V1: 1.4KON1.1, J2.+5V
5VOP: 0.1UF2.2, 13.2K.2, U$3.3
5VOP1: 0.1UF5.2, 13.2K1.2, U$6.3
12V: 0.1UF1.2, 0.33UF.2, J1.+12V, U$2.4, U$3.1
12V1: 0.1UF4.2, 0.33UF1.2, J2.+12V, U$5.4, U$6.1
B: 36K.2, 680K.2, AMP.IN-
B1: 36K1.2, 680K1.2, AMP1.IN-
FB: 1.32K.2, 100K.1, CBYP10NF.2, LD090.2
FB1: 1.32K1.2, 100K1.1, CBYP10NF1.2, LD001.2
GND: 0.1UF.2, 0.1UF1.1, 0.1UF2.1, 0.33UF.1, 1.32K.1, 1M.2, 1M(1206).1, 36K.1, AMP.-VEE, AMP.GND, CAP_POWER.-, CIN10UF.1, COUT10UF.2, GND2.1, GNDP.1, J1.GND1, J1.GND2, J1.GND3, LD090.3, LD090.4, LD090.TH, RF1.2, RI2.1, RR2.2, RT.2, U$1.P$1, U$1.P$2, U$2.11, U$3.2
GND1: 0.1UF3.2, 0.1UF4.1, 0.1UF5.1, 0.33UF1.1, 1.32K1.1, 1M1.2, 1M(1206)1.1, 36K1.1, AMP1.-VEE, AMP1.GND, CAP_POWER1.-, CIN10UF1.1, COUT10UF1.2, GND1.1, GNDP1.1, J2.GND1, J2.GND2, J2.GND3, LD001.3, LD001.4, LD001.TH, RF3.2, RI1.1, RR4.2, RT1.2, U$4.P$1, U$4.P$2, U$5.11, U$6.2
IN_AMP: 10KIN.2, AMP.IN+
IN_AMP1: 10KIN1.2, AMP1.IN+
IN_VOLTAGE: 10KIN.1, J1.IN
IN_VOLTAGE1: 10KIN1.1, J2.IN
unnamed: RB2.2, T4.2, T4.2@1
unnamed: RB2.1, T3.3
unnamed: RB1.2, T2.2, T2.2@1
unnamed: RB1.1, T1.3
unnamed: RF1.1, T2.3
unnamed: RF3.1, T4.3
ON: 1.4KON.2, AMP.SD
ON1: 1.4KON1.2, AMP1.SD
OUT_PIEZO: 10KOUT.2, OUTPIEZO+.1
OUT_PIEZO1: 10KOUT1.2, OUTPIEZO+1.1
SOURCE: 10KOUT.1, 680K.1, AMP.SOURCE
SOURCE1: 10KOUT1.1, 680K1.1, AMP1.SOURCE
V1: 0.1UF3.1, 100K1.2, AMP1.VCC, CBYP10NF1.1, COUT10UF1.1, LD001.1
V90: 0.1UF.1, 100K.2, AMP.VCC, CBYP10NF.1, COUT10UF.1, LD090.1
VF: RR1.2, RR2.1, U$2.2
VF1: RR3.2, RR4.1, U$5.2
VIN: 1M.1, 1M(1206).2, CAP_POWER.+, CIN10UF.2, LD090.5, LD090.8, RR1.1, T1.1
VIN1: 1M1.1, 1M(1206)1.2, CAP_POWER1.+, CIN10UF1.2, LD001.5, LD001.8, RR3.1, T3.1
VINS: 96V.1, T1.2
VINS1: 96V1.1, T3.2

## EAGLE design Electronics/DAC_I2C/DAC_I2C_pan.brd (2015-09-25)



Board: 2 copper layers, 81.9 x 71.8 mm, 56 parts (8 on the bottom side), 44 nets.

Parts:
C1, C7, C13, C19: 10n; C1206
C2, C6, C8, C12, C14, C18, C20, C24: 100n; C1206
C3, C9, C15, C21: 10u; C1206
C4, C5, C10, C11, C16, C17, C22, C23: 10uF; C1206
IC1, IC2, IC3, IC4: MCP1703DB; SOT223
J1, J2, J4, J5, J7, J8, J10, J11: RJ12STRAIGHT-I2C; RJ12-STRAIGHT-I2C
J3, J6, J9, J12: RJ12STRAIGHT; RJ12-STRAIGHT
SJ1, SJ2, SJ3, SJ4: SJ_2
U$1, U$3, U$7, U$10: AD5693R; MSOP10
U$2, U$4, U$5, U$6, U$8, U$9, U$11, U$12: STARGND; STAR

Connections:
3.3V: C4.1, C6.1, IC1.3, U$1.2, U$1.3
3.3V1: C11.1, C12.1, IC2.3, U$3.2, U$3.3
3.3V2: C17.1, C18.1, IC3.3, U$7.2, U$7.3
3.3V3: C23.1, C24.1, IC4.3, U$10.2, U$10.3
AGND: C1.2, C2.2, C3.2, C4.2, C5.2, C6.2, IC1.2, SJ1.3, U$1.4, U$1.5, U$5.AGND
AGND1: C7.2, C8.2, C9.2, C10.2, C11.2, C12.2, IC2.2, SJ2.3, U$3.4, U$3.5, U$4.AGND
AGND2: C13.2, C14.2, C15.2, C16.2, C17.2, C18.2, IC3.2, SJ3.3, U$7.4, U$7.5, U$8.AGND
AGND3: C19.2, C20.2, C21.2, C22.2, C23.2, C24.2, IC4.2, SJ4.3, U$10.4, U$10.5, U$11.AGND
DGND: J1.GND1, J1.GND2, J2.GND1, J2.GND2, U$2.DGND, U$2.GND, U$5.DGND, U$5.GND
DGND1: J4.GND1, J4.GND2, J5.GND1, J5.GND2, U$4.DGND, U$4.GND, U$6.DGND, U$6.GND
DGND2: J7.GND1, J7.GND2, J8.GND1, J8.GND2, U$8.DGND, U$8.GND, U$9.DGND, U$9.GND
DGND3: J10.GND1, J10.GND2, J11.GND1, J11.GND2, U$11.DGND, U$11.GND, U$12.DGND, U$12.GND
GND: J3.GND1, J3.GND2, U$2.AGND
GND1: J6.GND1, J6.GND2, U$6.AGND
GND2: J9.GND1, J9.GND2, U$9.AGND
GND3: J12.GND1, J12.GND2, U$12.AGND
unnamed: SJ1.2, U$1.6
unnamed: SJ2.2, U$3.6
unnamed: SJ3.2, U$7.6
unnamed: SJ4.2, U$10.6
SCL: J1.SCL, J2.SCL, U$1.7
SCL1: J4.SCL, J5.SCL, U$3.7
SCL2: J7.SCL, J8.SCL, U$7.7
SCL3: J10.SCL, J11.SCL, U$10.7
SDA: J1.SDA, J2.SDA, U$1.8
SDA1: J4.SDA, J5.SDA, U$3.8
SDA2: J7.SDA, J8.SDA, U$7.8
SDA3: J10.SDA, J11.SDA, U$10.8
VCC: C2.1, C3.1, C5.1, IC1.1, J1.+5V, J2.+5V, J3.+5V, SJ1.1, U$1.1
VCC1: C8.1, C9.1, C10.1, IC2.1, J4.+5V, J5.+5V, J6.+5V, SJ2.1, U$3.1
VCC2: C14.1, C15.1, C16.1, IC3.1, J7.+5V, J8.+5V, J9.+5V, SJ3.1, U$7.1
VCC3: C20.1, C21.1, C22.1, IC4.1, J10.+5V, J11.+5V, J12.+5V, SJ4.1, U$10.1
VDD: J1.+12V, J2.+12V, J3.+12V
VDD1: J4.+12V, J5.+12V, J6.+12V
VDD2: J7.+12V, J8.+12V, J9.+12V
VDD3: J10.+12V, J11.+12V, J12.+12V
VOUT: J3.I/O, U$1.10
VOUT1: J6.I/O, U$3.10
VOUT2: J9.I/O, U$7.10
VOUT3: J12.I/O, U$10.10
VREF: C1.1, U$1.9
VREF1: C7.1, U$3.9
VREF2: C13.1, U$7.9
VREF3: C19.1, U$10.9

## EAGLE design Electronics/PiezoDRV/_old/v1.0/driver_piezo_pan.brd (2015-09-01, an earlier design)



Board: 2 copper layers, 78.2 x 81.5 mm, 50 parts (12 on the bottom side), 22 nets.

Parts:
1M, 1M1: CA0002
1M(OP), 1M(OP)1, 10KIN, 10KIN1, 36K, 36K1, 680K, 680K1: R0805
AMP, AMP1: POWER_AMP_LME49811TB
CAP_POWER, CAP_POWER1: CAP200VCAP200V; CAP200V
CBYP, CBYP1: C0805
CIN, CIN1: C0805
COUT, COUT1: C0805
GND, GND1: PAD
GND2, GND3: 1X01
GNDP, GNDP2: 1X01
GNDP1, GNDP3: PAD
J1, J2: RJ12STRAIGHT-ANALOG; RJ12-STRAIGHT-ANALOG
LD001, LD090: TPS7A4001; S-PDSO-G08
OUTPIEZO, OUTPIEZO1: PAD
OUTPIEZOP, OUTPIEZOP1: 1X01
OUT_PIEZO, OUT_PIEZO1: R0805
R1, R2, R3, R4: R0805
RON, RON1: R0805
U$1, U$2: DISIPADOR
VIN, VIN1: 1X01
VINP, VINP1: PAD

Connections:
5V: J1.+5V, RON.2
5V1: J2.+5V, RON1.2
B: 36K.2, 680K.2, AMP.IN-
B1: 36K1.2, 680K1.2, AMP1.IN-
FB: CBYP.2, LD090.2, R1.1, R2.1
FB1: CBYP1.2, LD001.2, R3.1, R4.1
GND: 1M.2, 1M(OP).1, 36K.1, AMP.-VEE, AMP.GND, CAP_POWER.-, CIN.1, COUT.2, GND.P$1, GND2.1, GNDP.1, GNDP1.P$1, J1.GND1, J1.GND2, J1.GND3, LD090.3, LD090.4, LD090.TH, R2.2, U$1.P$1, U$1.P$2
GND1: 1M1.2, 1M(OP)1.1, 36K1.1, AMP1.-VEE, AMP1.GND, CAP_POWER1.-, CIN1.1, COUT1.2, GND1.P$1, GND3.1, GNDP2.1, GNDP3.P$1, J2.GND1, J2.GND2, J2.GND3, LD001.3, LD001.4, LD001.TH, R4.2, U$2.P$1, U$2.P$2
IN_AMP: 10KIN.1, AMP.IN+
IN_AMP1: 10KIN1.1, AMP1.IN+
IN_VOLTAGE: 10KIN.2, J1.IN
IN_VOLTAGE1: 10KIN1.2, J2.IN
ON: AMP.SD, RON.1
ON1: AMP1.SD, RON1.1
OUT_PIEZO: OUTPIEZO.P$1, OUTPIEZOP.1, OUT_PIEZO.1
OUT_PIEZO1: OUTPIEZO1.P$1, OUTPIEZOP1.1, OUT_PIEZO1.1
SOURCE: 680K.1, AMP.SOURCE, OUT_PIEZO.2
SOURCE1: 680K1.1, AMP1.SOURCE, OUT_PIEZO1.2
V1: AMP1.VCC, CBYP1.1, COUT1.1, LD001.1, R3.2
V90: AMP.VCC, CBYP.1, COUT.1, LD090.1, R1.2
VIN: 1M.1, 1M(OP).2, CAP_POWER.+, CIN.2, LD090.5, LD090.8, VIN.1, VINP.P$1
VIN1: 1M1.1, 1M(OP)1.2, CAP_POWER1.+, CIN1.2, LD001.5, LD001.8, VIN1.1, VINP1.P$1

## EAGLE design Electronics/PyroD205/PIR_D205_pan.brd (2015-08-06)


Board: 2 copper layers, 90.6 x 57.1 mm, 76 parts (0 on the bottom side), 44 nets.

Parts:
C1, C2, C3, C7, C8, C9, C13, C14, C15, C19, C20, C21: 4.7uF; C1206
C4, C6, C10, C12, C16, C18, C22, C24: 100nF; C1206
C5, C11, C17, C23: 10uF; C1206
IC1, IC2, IC3, IC4: TL072D; SO08
J1, J2, J3, J4: RJ12STRAIGHT-ANALOG; RJ12-STRAIGHT-ANALOG
R1, R11, R21, R31: 47k; R1206
R2, R3, R4, R12, R13, R14, R22, R23, R24, R32, R33, R34: 10k; R0805
R5, R6, R15, R16, R25, R26, R35, R36: 1k; R0805
R7, R17, R27, R37: 91; R1206
R8, R18, R28, R38: 390k; R1206
R9, R19, R29, R39: 200k; R1206
R10, R20, R30, R40: 51; R1206
U$1, U$2, U$3, U$4: D205B; TO5

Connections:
GND: C1.2, C2.2, C4.2, C5.2, C6.2, IC1.4, J1.GND1, J1.GND2, J1.GND3, R1.2, R6.1, R10.2, U$1.G
GND1: C7.2, C8.2, C10.2, C11.2, C12.2, IC2.4, J2.GND1, J2.GND2, J2.GND3, R11.2, R16.1, R20.2, U$2.G
GND2: C13.2, C14.2, C16.2, C17.2, C18.2, IC3.4, J3.GND1, J3.GND2, J3.GND3, R21.2, R26.1, R30.2, U$3.G
GND3: C19.2, C20.2, C22.2, C23.2, C24.2, IC4.4, J4.GND1, J4.GND2, J4.GND3, R31.2, R36.1, R40.2, U$4.G
unnamed: C6.1, R1.1, R4.1, U$1.S
unnamed: C3.2, IC1.1, R2.1, R5.2
unnamed: IC1.2, R5.1, R6.2
unnamed: C1.1, R2.2, R7.1
unnamed: C2.1, IC1.3, R3.2
unnamed: C3.1, R3.1, R4.2
unnamed: IC1.6, R7.2, R8.1
unnamed: IC1.7, J1.IN, R8.2
unnamed: IC1.5, R9.1, R10.1
unnamed: C12.1, R11.1, R14.1, U$2.S
unnamed: C9.2, IC2.1, R12.1, R15.2
unnamed: IC2.2, R15.1, R16.2
unnamed: C7.1, R12.2, R17.1
unnamed: C8.1, IC2.3, R13.2
unnamed: C9.1, R13.1, R14.2
unnamed: IC2.6, R17.2, R18.1
unnamed: IC2.7, J2.IN, R18.2
unnamed: IC2.5, R19.1, R20.1
unnamed: C18.1, R21.1, R24.1, U$3.S
unnamed: C15.2, IC3.1, R22.1, R25.2
unnamed: IC3.2, R25.1, R26.2
unnamed: C13.1, R22.2, R27.1
unnamed: C14.1, IC3.3, R23.2
unnamed: C15.1, R23.1, R24.2
unnamed: IC3.6, R27.2, R28.1
unnamed: IC3.7, J3.IN, R28.2
unnamed: IC3.5, R29.1, R30.1
unnamed: C24.1, R31.1, R34.1, U$4.S
unnamed: C21.2, IC4.1, R32.1, R35.2
unnamed: IC4.2, R35.1, R36.2
unnamed: C19.1, R32.2, R37.1
unnamed: C20.1, IC4.3, R33.2
unnamed: C21.1, R33.1, R34.2
unnamed: IC4.6, R37.2, R38.1
unnamed: IC4.7, J4.IN, R38.2
unnamed: IC4.5, R39.1, R40.1
VCC: C4.1, C5.1, IC1.8, J1.+5V, R9.2, U$1.D
VCC1: C10.1, C11.1, IC2.8, J2.+5V, R19.2, U$2.D
VCC2: C16.1, C17.1, IC3.8, J3.+5V, R29.2, U$3.D
VCC3: C22.1, C23.1, IC4.8, J4.+5V, R39.2, U$4.D

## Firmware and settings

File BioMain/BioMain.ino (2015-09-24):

/**************
 * LIBRAIRIES
 **************/

//MultiThread
#include <NilRTOS.h>

//Lib to access memory with SPI
#include <SPI.h>

// Library that allows to start the watch dog allowing automatic reboot in case of crash
// The lowest priority thread should take care of the watch dog
#include <avr/wdt.h>

// http://www.arduino.cc/playground/Code/Time
// We need to deal with EPOCH
#include <Time.h>

/******************
 * DEFINE CARD TYPE
 ******************/

#define TYPE_FTIR  1 

#define DIGITAL_5       5//D5 OC4A  
#define DIGITAL_6       6//D6 OC4D
#define DIGITAL_7       7//D7
#define DIGITAL_8       8//D8 A8
#define DIGITAL_9       9//D9 OC4B, OC1A, PCINT5
#define DIGITAL_10      10//D10 A10
#define DIGITAL_11      11//D11
#define DIGITAL_13      13//D13

#define ANALOG_0     18//0
#define ANALOG_1     19//A1
#define ANALOG_2     20//A2
#define ANALOG_3     21//A3
#define ANALOG_4     22//A4

/**************************************
 * ACTIVE THREAD DEPENDING CARD TYPE
 **************************************/

#ifdef TYPE_FTIR
  #define MODEL_ZIGBEE       //Serial Com on Zigbee antenna SZ05
  #define I2C_EEPROM 80      //I2C EEPROM memory 512k or 1M (m24512)
  #define EEPROM_ENABLE DIGITAL_11
  
  #define IR_FAN      DIGITAL_5
  #define IR_SRC      DIGITAL_6
  #define PUMP_12V    DIGITAL_9
  
  //#define TEMPERATURE_CTRL 1    //DS18B20+ OneWire inputs
    //#define PELTIER_PID  1    //Peltier Cooling Thread
    
    #define TEMP_ALU       ANALOG_0    //PID COLD
    #define TEMP_IR        ANALOG_1 
    #define TEMP_SINK      ANALOG_2
    #define TEMP_SENSOR    ANALOG_3    //PID HOT

    #define PELTIER_50     DIGITAL_7   //PWM
    #define PELTIER_75     DIGITAL_10  //PWM 

  #define IR_SENSE      1
    #define I2C_IR_INTENSITY  104   //change the digital input here with the I2 address of the ADC
    #define IR_INTENSITY      ANALOG_4   
  
  #define PIEZO_DRV           1 //piezo driver on DAC1220 via SPI
    #define PIEZO_SELECT      DIGITAL_8     

  #define THR_MONITORING     1  // starts the blinking led and the watch dog counter 
  #define MONITORING_LED     DIGITAL_13
    
#endif

/***********************
 * SERIAL, LOGGER AND DEBUGGER
 ************************/

#define THR_SERIAL        1

#ifdef MODEL_ZIGBEE
#define THR_ZIGBEE      1 // communication process on Serial1
#endif

/*******************************
 * CARD DEFINITION (HARD CODED)
 *******************************/

#ifdef IR_SENSE
  #define PARAM_STEP_NUMBER  0
  #define PARAM_I2C_IR       1
  #define PARAM_AN_IR        2
#endif

#ifdef     TEMPERATURE_CTRL
  #define PARAM_TEMP_ALU     3
  #define PARAM_TEMP_IR      4
  #define PARAM_TEMP_SENSOR  5
  #define PARAM_TEMP_SINK    6
  #if defined (PELTIER_PID)
    #define PARAM_TARGET_SENSOR_TEMP          7
    #define PARAM_TEMP_IR_MAX                 8
    #define PARAM_TEMP_SINK_MAX               9
    #define PARAM_TEMP_SENSOR_MIN             10
    #define PARAM_PID_REGULATION_TIME_WINDOW  11 //in [ms]
  #endif
#endif

/******************
 * FLAG DEFINITION
 ******************/

//Status parameters giving the system state
#define PARAM_STATUS          12

#define STARTUP               0
#define COOLING               1
#define PUMPING               2
#define ACQUIRE               3
#define ERROR_TEMP_IR_HOT     4
#define ERROR_TEMP_SINK_HOT   5
#define ERROR_TEMP_IR_FAIL    6
#define ERROR_TEMP_SINK_FAIL  7
#define ERROR_TEMP_SENSE_FAIL 8
#define ERROR_TEMP_ALU_FAIL   9
#define ERROR_IR_SENSE_FAIL   10
#define IR_FAN_ON             11
#define COOLING_FAN_ON        12

/*********
 * Autoreboot parameters
 *********/
#define MAX_EPOCH  (long int) 1500000000  //epoch cannot be forced externally  after  Fri, 14 Jul 2017 02:40:00 GMT
#define MIN_EPOCH  (long int) 1400000000  //epoch cannot be forced externally  before Tue, 13 May 2014 16:53:20 GMT
#define AUTOREBOOT 36000 // we will reboot automatically every 1h ... bad trick to prevent some crash problems of ethernet ...
uint16_t autoreboot=0;
/*********
 * SETUP
 *********/

void setup() {
  delay(2000);
  Serial.begin(9600);
  delay(1000);  
  //set memory enable pin
  pinMode(EEPROM_ENABLE,OUTPUT);
  //set analog read on IR_INTENSITY
  pinMode(IR_INTENSITY,INPUT); 
  //set enable pin for the DAC (piezo driver 0-5V reference)
  pinMode(PIEZO_SELECT,OUTPUT);
  digitalWrite(PIEZO_SELECT,HIGH);
  pinMode(SS,OUTPUT);
  pinMode(SCK, OUTPUT);
  pinMode(MISO, INPUT);
  pinMode(MOSI, OUTPUT);
  //set hexfets to output (to be set in an external interruption routine so everything is not up all the time but just on request)
  pinMode(IR_FAN,OUTPUT);
  digitalWrite(IR_FAN,HIGH);
  pinMode(IR_SRC,OUTPUT);
  digitalWrite(IR_SRC,HIGH);
  pinMode(PUMP_12V,OUTPUT);
  pinMode(PELTIER_50,OUTPUT);
  pinMode(PELTIER_75,OUTPUT);
  setupParameters();

    /*
    ADCSRA |= (_BV(ADEN)); // Turn on ADC
    ADCSRB |= (_BV(ACME)); // Turn on Analog Comparator    
    PRR0 = 0x00;  // Power Reduction Registers  
    PRR1 = 0x00;  // set to 0b0, 0b0
    MCUCR &= ~(_BV(JTD)); // Enable on-chip debug system
    DIDR0 = 0x00; // Analog to digital pin's digital input buffer is turned on*/

  setSafeConditions(false);
  nilSysBegin();

}

void loop() {
  
  /*
  delay(2000);
  digitalWrite(PUMP_12V ,HIGH);*/

}

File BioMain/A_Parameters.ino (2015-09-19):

/*********************************************
 * This file is used to declare the parameters
 * table used by the program.
 * 
 * We use the EEPROM for saving the parameters 
 * changed by the user during the functionment 
 * of the Bioreactor.
 * 
 * The parameter are loaded during the boot.
 * 
 * All change to important parameters are saved 
 * to the EEPROM
 *********************************************/

//internal arduino 512 bits EEPROM
#include <avr/eeprom.h>
#define EEPROM_MIN_ADDR            0
#define EEPROM_MAX_ADDR          511
//Lock byte as last position on the EEPROM
#define LOCKER EEPROM_MAX_ADDR

#if defined (PIEZO_DRV) && defined(I2C_IR_INTENSITY)
  #define EEPROM_IR_FLAG (EEPROM_MAX_ADDR-1)
#endif

// If the MAX_PARAM change you need to change the pointer in the EEPROM
#define MAX_PARAM 25   
#define EE_START_PARAM           0 // We save the parameter from byte 0 of EEPROM
#define EE_LAST_PARAM            (MAX_PARAM*2-1) // The last parameter is stored at byte 50-51

//When parameters are set (and saved) an event is recorded (256-281 : A-Z + .... (if more parameters than 26))
#define EVENT_SAVE_ALL_PARAMETER     255
#define EVENT_PARAMETER_SET          256

// value that should not be taken into account
// in case of error the parameter is set to this value
#define ERROR_VALUE  -32768

int parameters[MAX_PARAM];

void setupParameters() {
  //We copy all the value in the parameters table
  eeprom_read_block((void*)parameters, (const void*)EE_START_PARAM, MAX_PARAM*2);
}

int getParameter(byte number) {
  return parameters[number];
}

void setParameterBit(byte number, byte bitToSet) {
   bitSet(parameters[number], bitToSet);
  // parameters[number]=parameters[number] | (1 << bitToSet);
}

void clearParameterBit(byte number, byte bitToClear) {
   bitClear(parameters[number], bitToClear);
  // parameters[number]=parameters[number] & ( ~ (1 << bitToClear));
}

byte getParameterBit(byte number, byte bitToRead) {
   return bitRead(parameters[number], bitToRead);
  // return (parameters[number] >> bitToRead ) & 1;
}

void setParameter(byte number, int value) {
  parameters[number]=value;
}

void saveParameters() {
  for (byte i=0; i<MAX_PARAM; i++) {
    eeprom_write_word((uint16_t*) EE_START_PARAM+i, parameters[i]);
  }
  writeLog(EVENT_SAVE_ALL_PARAMETER, 0);
}

/*
This will take time, around 4 ms
 This will also use the EEPROM that is limited to 100000 writes
 */
void setAndSaveParameter(byte number, int value) {
  parameters[number]=value;
  //The address of the parameter is given by : EE_START_PARAM+number*2
  eeprom_write_word((uint16_t*) EE_START_PARAM+number, value);

  writeLog(EVENT_PARAMETER_SET+number, value);
}


void printParameter(Print* output, byte number){
  output->print(number);
  output->print("-");
  if (number>25) {
    output->print((char)(floor(number/26) + 64));
  } else {
    output->print(" ");
  }
  output->print((char)(number-floor(number/26)*26 + 65));
  output->print(": ");
  output->println(parameters[number]);
}

void printParameters(Print* output) {
  for (byte i = 0; i < MAX_PARAM; i++) {
    printParameter(output, i);
  }
}

#ifdef EEPROM_DUMP
// code from http://www.arduino.cc/playground/Code/EepromUtil
void getStatusEEPROM(Print* output) {
  int bytesPerRow = 16;
  int i;
  int j;
  byte b;
  char buf[4];

  j = 0;

  // go from first to last eeprom address
  for (i = EEPROM_MIN_ADDR; i <= EEPROM_MAX_ADDR; i++) {
    if (j == 0) {
      sprintf(buf, "%03X", i);
      output->print(buf);
      output->print(F(": "));
    }

    // read current byte from eeprom
    b = EEPROM.read(i);
    sprintf(buf, "%02X ", b);
    j++;
    if (j == bytesPerRow) {
      j = 0;
      output->println(buf);
      nilThdSleepMilliseconds(25);
    }
    else {
      output->print(buf);
    }
  }
}
#endif

uint8_t printCompactParameters(Print* output) {
  printCompactParameters(output, MAX_PARAM);
}

uint8_t printCompactParameters(Print* output, byte number) {
  if (number > MAX_PARAM) {
    number=MAX_PARAM;
  }
  byte checkDigit=0;

  // we first add epoch
  checkDigit^=toHex(output, (long)now());
  for(int i = 0; i < number; i++) {
    int value=getParameter(i);
    checkDigit^=toHex(output, value);
  }
  checkDigit^=toHex(output, (int)getQualifier());
  toHex(output, checkDigit);
  output->println("");
}

/* The qualifier represents the card ID and is stored just after the last parameter */
uint16_t getQualifier() {
  return eeprom_read_word((uint16_t*)(EE_START_PARAM+MAX_PARAM*2));
}

void setQualifier(uint16_t value) {
  eeprom_write_word((uint16_t*)(EE_START_PARAM+MAX_PARAM*2), value);
}

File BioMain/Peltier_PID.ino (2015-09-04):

#ifdef PELTIER_PID
#ifdef TEMPERATURE_CTRL

#include <PID_v1.h>

//#define DEBUG_PID

void pid_ctrl();
void PIDSetup();

int count=0;
double coolingRegInput;
double coolingRegOutput;
double coolingRegSetpoint;

unsigned long coolingRegWindowStartTime;
//Specify the heating regulation links and initial tuning parameters //Kp=100; Ti=0.2 Td=5 are initial testing param.
//PID object definition can be found in PID library (to include for compilation)
PID coolingRegPID(&coolingRegInput, &coolingRegOutput, &coolingRegSetpoint, 7000,15,1600, DIRECT);


NIL_WORKING_AREA(waThread_Peltier, 128); // minimum of 16 The momory change with time
NIL_THREAD(Thread_Peltier, arg) 
{
  

  nilThdSleepMilliseconds(5000); 
  //initialize the Peltier elements
  pinMode(PELTIER_50, OUTPUT);
  pinMode(PELTIER_75, OUTPUT);
  //Todo : update heatingSetup when a parameter is changed
  PIDSetup();
  
  while(TRUE){
     
     #ifdef DEBUG_PID
     if(count%30==0)
      Serial.print(getParameter(PARAM_TEMP_SENSOR));
    count=(count+1)%101;
    #endif
    
    pid_ctrl();
    nilThdSleepMilliseconds(500);  //refresh every 500ms
  }
}


/*Temperature PID Control addressing relay*/
void pid_ctrl()
{
  float exactPresentTime;
  
    coolingRegInput = -1*getParameter(PARAM_TEMP_SENSOR);
    coolingRegSetpoint = -1*getParameter(PARAM_TARGET_SENSOR_TEMP);
    coolingRegPID.Compute();        // the computation takes only 30ms!
    // turn the output pin on/off based on pid output
    exactPresentTime = millis();

  if (exactPresentTime - coolingRegWindowStartTime > getParameter(PARAM_PID_REGULATION_TIME_WINDOW)) { 
    //time to shift the Relay Window
    coolingRegWindowStartTime += getParameter(PARAM_PID_REGULATION_TIME_WINDOW);
  }
  
   if((coolingRegOutput > exactPresentTime - coolingRegWindowStartTime) 
    //&& (getParameter(PARAM_TEMP_SINK)<getParameter(PARAM_TEMP_SINK_MAX))
    && (getParameter(PARAM_TEMP_SENSOR)>getParameter(PARAM_TEMP_SENSOR_MIN))
    && (getParameter(PARAM_TEMP_SENSOR) != 0xFF) && (getParameter(PARAM_TEMP_SINK)!=0xFF))
  {
    Serial.println("on");
    digitalWrite(PELTIER_75, HIGH);
    digitalWrite(PELTIER_50, HIGH);
  }  
  else 
  {
    Serial.println("off");
    digitalWrite(PELTIER_75, LOW);
    digitalWrite(PELTIER_50, LOW);
  } 
  
}


// see the rest of oliver's code for sanity checks

void PIDSetup()
{ 
  coolingRegPID.SetOutputLimits(0, getParameter(PARAM_PID_REGULATION_TIME_WINDOW));          //what is heating regulation time windows ???
  //turn the PID on, cf. PID library
  coolingRegPID.SetMode(AUTOMATIC);                 
  //set PID sampling time to 10000ms                   //possibly set a timer condition with a nilsleep instead
  coolingRegPID.SetSampleTime(10000);

  coolingRegWindowStartTime = millis();
  // heatingRegSetpoint = getParameter(PARAM_TEMP_MAX);
}

#endif
#endif

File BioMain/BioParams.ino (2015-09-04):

#define ERROR_VALUE  -32768


// Definition of all events to be logged
#define EVENT_ARDUINO_BOOT           1
#define EVENT_ARDUINO_SET_SAFE       2

#define EVENT_TEMP_IR_FAILED        50
#define EVENT_TEMP_IR_RECOVER       51
#define EVENT_TEMP_SINK_FAILED      52
#define EVENT_TEMP_SINK_RECOVER     53
#define EVENT_TEMP_SENSOR_FAILED    54
#define EVENT_TEMP_SENSOR_RECOVER   55
#define EVENT_TEMP_ALU_FAILED       54
#define EVENT_TEMP_ALU_RECOVER      55

#define EVENT_ERROR_NOT_FOUND_ENTRY_N  150


void resetParameters() { 
  
#ifdef     TEMPERATURE_CTRL
  setAndSaveParameter(PARAM_TEMP_IR, ERROR_VALUE);
  setAndSaveParameter(PARAM_TEMP_SINK, ERROR_VALUE);
  setAndSaveParameter(PARAM_TEMP_SENSOR, ERROR_VALUE);
  setAndSaveParameter(PARAM_TEMP_ALU, ERROR_VALUE);
  #if defined (PELTIER_PID)
    setAndSaveParameter(PARAM_TEMP_IR_MAX, 7000);
    setAndSaveParameter(PARAM_TEMP_SINK_MAX, 7000);
  #endif
  
  #ifdef TEMP_PID
  setAndSaveParameter(PARAM_TARGET_SENSOR_TEMP, -500);
  setAndSaveParameter(PARAM_PID_REGULATION_TIME_WINDOW, 5000);
  setAndSaveParameter(PARAM_TEMP_SENSOR_MIN, -1000);  
  //setAndSaveParameter(PARAM_MIN_TEMPERATURE, 1000);  // not used but could be used for safety
  //setAndSaveParameter(PARAM_MAX_TEMPERATURE, 4000);  // not used but could be used for safety  
  #endif
  
#endif

  setAndSaveParameter(PARAM_STATUS, 0); // 0b0000 1111 activate food_control, ph_control, gas_control, stepper_control

}

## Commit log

2015-07-16 first push with incomplete CAD files and datasheets
    [Assembly.fcstd, Bench.stl, Charriot.fcstd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]
2015-07-17 CAD work on progress, missing splitter hat screws and sensor support
    [Assembly.fcstd, Assembly_3.fcstd, Assembly_4.fcstd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]
2015-07-18 CAD almost done, minor correction on Splitter_Hat_1 to come
    [Assembly_3.fcstd, Assembly_4.fcstd, Assembly_5.fcstd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]
2015-07-19 corrected hat, added assembled and split views
    [Assembly_6.fcstd, Eclate.fcstd, Splitter_Hat_1.fcstd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]
2015-07-21 IR source T°C at 120°C : corrected bench design, added 2D woodcuts as heat insulators to protect ABS prints
    [Assembly_6.fcstd, Bench.stl, Eclate.fcstd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]
2015-07-26 added heat sink to the design
    [Assembly_6.fcstd, Bench.stl, Bench_new.stl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]
2015-07-28 started main board design
    [MetalCut.fcstd]
2015-07-28 Create DAC20
    DAC 20 bits device
2015-08-02 started electronic design of the main board
    [Assembly_6.fcstd, Bench_new.stl, FTIR_v0.1.brd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]
2015-08-04 main board Oudini on the way, 2.5V ref generator missing for the DAC stage, guard ring to be added on C1 C2 (see datasheet DAC1220)
    [FTIR_v0.1.brd, FTIR_v0.1_noCC2.brd, FTIR_v0.1_noCC2.sch]
2015-08-05 finalisation of main FTIR board (Oudini)
    [FTIR_v0.1_noCC2.brd, FTIR_v0.1_noCC2.sch]
2015-08-06 finished sensor board for D205B, finished main board Oudini v1.0, Generated Gerbers, modified CAD for PCB support
    [Assembly_6.fcstd, Bench_new.stl, FTIR_v0.1.brd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]
2015-08-10 added slit for piezo driver PCB, actualized lpatini.lbr
    [Assembly_6.fcstd, Bench.stl, Bench_new.stl]
2015-08-11 added piezo driver, slight change on the optical bench CAD
    [Bench_new.stl, driver_piezo.brd, driver_piezo.sch]
2015-08-12 finished pin mapping
2015-09-01 started assembly, some code modifications according to SolarBoard (locker, small log) need to reduce the log further and code the scanning routine
    [driver_piezo_pan.brd]
2015-09-04 changed pin mapping, PID need to be remanufactured (too low thermal insulation between hot and cold)
    [A_Parameters.ino, BioMain.ino, BioParams.ino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]
2015-09-12 modified logger I2C to avoid crash on memory erase, added test code for the IR sensor P205B
    [BioMain.ino, I2C.ino, Logger_I2C.ino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]
2015-09-19 initiated code for DAC1220 contorl over SPI, need to review the log (log-on-step) & disable wdt on memory swipe & end DAC1220 configure
2015-09-19 added configuration code and stepping code for DAC1220, yield a 2.5-5V variation over 65535 steps
2015-09-24 added 96 voltage stabilizer t othe Piezo Driver Board
    [driver_piezo.brd, driver_piezo.sch, driver_piezo2.brd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]
2015-09-25 development board for MSOP10 16 bits I2C DAC
    [DAC_I2C.brd, DAC_I2C.sch, DAC_I2C_pan.brd]
2015-09-25 corrections on piezo driver v2.0, generated gerbers
    [driver_piezo2.GBL, driver_piezo2.GBO, driver_piezo2.GBP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]
2016-08-27 update project current state and TODOs

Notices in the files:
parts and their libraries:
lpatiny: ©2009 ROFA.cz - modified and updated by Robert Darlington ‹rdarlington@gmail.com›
